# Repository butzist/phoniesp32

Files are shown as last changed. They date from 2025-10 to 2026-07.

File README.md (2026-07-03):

# phoniesp32 🎶🔋

A **kid-friendly jukebox** powered by the **ESP32**, inspired by
[Phoniebox](https://phoniebox.de). Unlike the original Raspberry Pi–based
version, **phoniesp32** is designed to be **battery-operated, low-power, and
ultra-portable**.

> ⚠️ Work in Progress — Contributions, ideas, and wiring tips are very welcome!

---

## 📥 Download Latest Firmware

[Download Firmware](https://github.com/butzist/phoniesp32/actions) (download the
`firmware` artifact from the latest run on main)

## ✨ Features

- **ESP32-based jukebox**: replaces the Raspberry Pi with an ESP32-C6.
- **Low-power & battery-ready**: runs on a Li-ion cell with charging and
  buck-boost converter.
- **Bare-metal Rust firmware**: built on the [`embassy`](https://embassy.dev/)
  async embedded framework.
- **Rust-powered Web UI**: implemented with [Dioxus](https://dioxuslabs.com/)
  and served directly from the ESP32.
- **Audio transcoding & upload**: convert music files via the web frontend to
  IMA ADPCM, upload to device, and play back instantly.
- **RFID support**: scan S50 fobs with a MFRC522 module to trigger playlists.
- **Affordable**: target build cost **under 50 CHF**.

---

## 🛠 Components

- **MCU**: ESP32-C6
- **Charging/Power**: BQ24073 (Li-ion charger), TSP631000 (buck-boost converter)
- **Battery**: Li-ion cell (e.g. 18650)
- **Audio**: MAX98357 (I2S DAC + amplifier)
- **Storage**: SD card adapter
- **RFID**: MFRC522 module + S50 RFID fobs

---

## 🏗 Build Options

1. **[DIY Breakout Board Build](./docs/diy-build.md)** - Build using
   off-the-shelf breakout boards on a breadboard or prototype board (~25 CHF)
2. **[PCB Build](./docs/pcb-build.md)** - Build using a compact and robust
   custom PCB board (~30 CHF)
3. **[PCBWay Shared Project](https://www.pcbway.com/project/shareproject/PhoniESP32_v1_2_d32752ab.html)**
   Order PCB on PCBWay with optional partial assembly of basic parts. Tutorial
   TBD

### 🏆 Sponsored by PCBWay

I'm grateful to [PCBWay](https://www.pcbway.com) for sponsoring this project!

The PCB and assembly quality was excellent, and their BOM review caught a few
mistakes I made in component selection — super helpful. I used the sponsorship
to fix minor bugs from v1 (charging indicator) and produce a version that can be
hand soldered. I opted for partial assembly (resistors, capacitors, LEDs) and am
practicing soldering connectors and ICs myself. Update and tutorial TBD — while
waiting, check out my project on PCBWay's shared project platform.

<a href="https://www.pcbway.com/project/shareproject/PhoniESP32_v1_2_d32752ab.html">
    PCB from PCBWay
</a>

---

## 🚧 Project Status

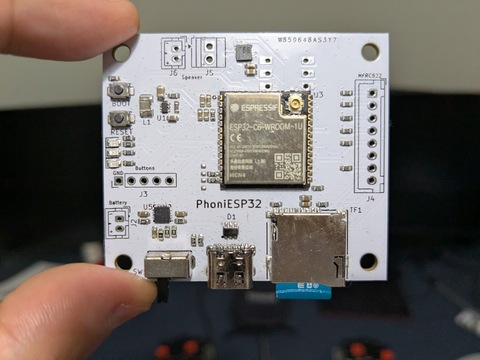
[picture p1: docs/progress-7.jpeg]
Photo of PCB

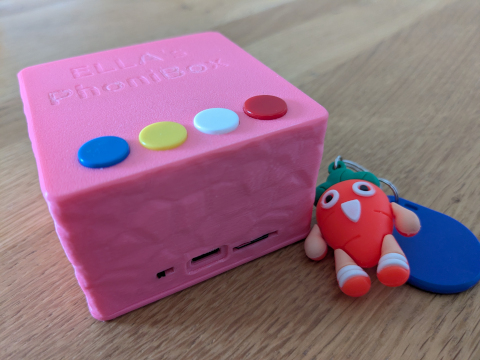
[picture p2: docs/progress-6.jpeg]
Photo of PCB integration


### Backlog

- [x] Hardware
  - [x] Prototype on breadboard
  - [x] Soldered Prototype
  - [x] Battery charger
  - [x] Schematics
  - [x] Custom PCB
  - [x] Design and 3D print case
- [x] UI (Dioxus)
  - [x] File transcoding
  - [x] Served from device
  - [x] Show last scanned RFID tag ID
  - [x] Switch to Bluma CSS
  - [x] Playback control
  - [x] Store RIFF INFO chunk for artist/title
  - [x] Associate file with RFID tag
  - [x] Configure Wi-Fi settings
  - [x] Playlists
  - [x] List known tags
  - [x] List uploaded files
  - [x] Continue file upload
  - [x] Styling
  - [x] Do not use CDN
  - [x] Update to stable Dioxus 0.7
- [ ] Firmware (Embassy)
  - [x] Fallback to Wi-Fi AP mode
  - [x] Audio pipeline (I2S → MAX98357)
  - [x] SD card access
  - [x] Playback control via buttons
  - [x] Playback control via RFID tags
  - [x] Pause playback
  - [x] Playlists
  - [x] Use RIFF INFO chunk for artist/title
  - [x] Fix concurrent access to file system
  - [x] mDNS responder
  - [x] Turn off Wi-Fi when on battery power
  - [x] Enable Wi-Fi temporarily by pressing volume up+down simultaneously for
        3s
  - [x] Captive portal and DHCP server for WiFi access point
  - [x] Speed up SD access/upload (SD card was bad - turns out cheap SD cards
        are bad at SPI)
  - [ ] Playback control via BLE
  - [x] SD card partitioning support
  - [x] Update to stable esp-hal 1.0
- [x] Web API (picoserve)
  - [x] Associate file with RFID tag
  - [x] Playback control
  - [x] Playback status
  - [x] Last scanned RFID tag ID
  - [x] Configure Wi-Fi settings
  - [x] List known tags
  - [x] List uploaded files
  - [x] Playlists
- [ ] Command line utility
  - [x] Transcode
  - [ ] Upload
  - [ ] Playback control
  - [ ] Associate
- [x] Build system
  - [x] Build and bundle all components
  - [x] Build via GitHub actions
- [ ] Upstream fixes
  - [ ] `dioxus`: Support sass:color.channel()
  - [x] `mfrc522`: async / IRQ support implemented in
        [mfrc522-async](https://github.com/butzist/mfrc522-async)
- [ ] Documentation
  - [x] [API Documentation](./API.md)
  - [x] [DIY Build Instructions](./docs/diy-build.md)
  - [ ] Hand soldering tutorial
  - [ ] Video tutorial

---

## 🤝 Contributing

Want to help build the cheapest, most fun, and hackable jukebox for kids?

- Review my code! I bet there are many possibilities to optimize power/memory
  usage
- Implement any of the missing features
- Share your ideas

PRs, issues, and ideas are always welcome!

---

## 📜 License

MIT License — free to use, hack, and share.

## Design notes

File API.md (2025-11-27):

# PhonieSP32 API Documentation

This document describes the REST API endpoints provided by the PhoniESP32
firmware web server.

## Base URL

All endpoints are relative to `http://<device-ip>`

**Default IP Address:** `192.168.42.1` (when device is in Access Point mode)

**Default WiFi Credentials:**

- SSID: `phoniesp32`
- Password: `12345678`

## Data Types

### AudioMetadata

```json
{
  "artist": "string (max 31 chars)",
  "title": "string (max 31 chars)",
  "album": "string (max 31 chars)",
  "duration": "number (seconds)"
}
```

### FileEntry

```json
{
  "name": "string (max 8 chars)",
  "metadata": "AudioMetadata"
}
```

### Association

```json
{
  "fob": "string (max 8 chars)",
  "files": ["FileEntry"]
}
```

### LastFob

```json
{
  "last_fob": "string (max 8 chars) or null"
}
```

### StatusResponse

```json
{
  "position_seconds": "number",
  "state": "Playing|Paused|Stopped",
  "index_in_playlist": "number",
  "playlist_name": "string (max 8 chars) or null"
}
```

### CurrentPlaylistResponse

```json
{
  "playlist_name": "string (max 8 chars)",
  "files": [{
    "file": "string (max 8 chars)",
    "metadata": "AudioMetadata"
  }]
}
```

### DeviceConfig

```json
{
  "ssid": "string",
  "password": "string"
}
```

## Endpoints

### Files

#### GET /api/files

List all audio files on the device.

**Response:** Array of `FileEntry`

#### GET /api/files/{filename}

Get metadata for a specific audio file.

**Parameters:**

- `filename`: string (max 8 chars, without .wav extension)

**Response:** `AudioMetadata` or 404 if not found

#### POST /api/files/{filename}

Create an empty audio file for chunked upload.

**Parameters:**

- `filename`: string (max 8 chars, without .wav extension)

**Response:** 201 Created on success

#### PATCH /api/files/{filename}

Upload a chunk of data to an existing audio file.

**Parameters:**

- `filename`: string (max 8 chars, without .wav extension)

**Headers:**

- `Upload-Offset`: number - Byte offset to start writing at

**Request Body:** Raw audio file chunk data

**Response:** 204 No Content on success, 404 if file doesn't exist, 400 if offset is larger than file size

#### HEAD /api/files/{filename}

Get the current size of an audio file.

**Parameters:**

- `filename`: string (max 8 chars, without .wav extension)

**Response Headers:**

- `Upload-Offset`: number - Current file size in bytes

**Response:** 200 OK on success, 404 if file doesn't exist

#### PUT /api/files/{filename}

Upload an entire audio file to the device (legacy endpoint).

**Parameters:**

- `filename`: string (max 8 chars, without .wav extension)

**Request Body:** Raw audio file data (WAV format, 44100 kHz, IMA ADPCM). Use
transcoder!

**Response:** 204 No Content on success

### Chunked Upload Workflow

For reliable file uploads with resume capability:

1. **Create file:** `POST /api/files/{filename}` - Creates empty file
2. **Upload chunks:** `PATCH /api/files/{filename}` with `Upload-Offset` header - Upload data in chunks
3. **On error:** Check progress with `HEAD /api/files/{filename}` and resume from last valid offset
4. **Repeat steps 2-3** until upload complete

**Example chunked upload with error handling:**
```bash
# Create empty file
curl -X POST http://192.168.42.1/api/files/song1

# Upload first chunk
curl -X PATCH http://192.168.42.1/api/files/song1 \
  -H "Upload-Offset: 0" \
  --data-binary @chunk1.bin

# Upload second chunk (simulating network error)
curl -X PATCH http://192.168.42.1/api/files/song1 \
  -H "Upload-Offset: 1024" \
  --data-binary @chunk2.bin || echo "Upload failed, checking progress..."

# Check current file size to resume from
CURRENT_SIZE=$(curl -I http://192.168.42.1/api/files/song1 | grep Upload-Offset | cut -d' ' -f2 | tr -d '\r')
echo "Current file size: $CURRENT_SIZE bytes"

# Resume upload from current size
curl -X PATCH http://192.168.42.1/api/files/song1 \
  -H "Upload-Offset: $CURRENT_SIZE" \
  --data-binary @chunk2.bin

# Continue with remaining chunks...
```

### Associations (RFID FOBs)

#### GET /api/last_fob

Get the last scanned RFID FOB.

**Response:** `LastFob`

#### GET /api/associations

List all FOB associations.

**Query Parameters:**

- `fob` (optional): Filter by specific FOB name

**Response:**

- Without `fob` parameter: Array of `Association`
- With `fob` parameter: Single `Association` or 404 if not found

#### POST /api/associations

Create a new FOB association.

**Request Body:**

```json
{
  "fob": "string (max 8 chars)",
  "files": ["string (max 8 chars)"]
}
```

**Response:** 204 No Content on success

### Playback Control

#### GET /api/playback/status

Get current playback status.

**Response:** `StatusResponse`

#### GET /api/playback/current_playlist

Get current playlist with metadata.

**Response:** `CurrentPlaylistResponse` or null if not playing

#### POST /api/playback/play

Start playback.

**Request Body:**

```json
{
  "file": "string (max 8 chars)", // Play single file
  // OR
  "playlist": ["string (max 8 chars)"], // Play list of files
  // OR
  "playlistref": "string (max 8 chars)" // Play playlist by FOB name
}
```

**Response:** 204 No Content on success

#### POST /api/playback/stop

Stop playback.

**Response:** 204 No Content on success

#### POST /api/playback/pause

Toggle pause/play state.

**Response:** 204 No Content on success

#### POST /api/playback/volume_up

Increase volume.

**Response:** 204 No Content on success

#### POST /api/playback/volume_down

Decrease volume.

**Response:** 204 No Content on success

#### POST /api/playback/next

Skip to the next track in the current playlist.

**Response:** 204 No Content on success

#### POST /api/playback/previous

Skip to the previous track in the current playlist.

**Response:** 204 No Content on success

### Configuration

#### PUT /api/config

Update device configuration (WiFi settings).

**Request Body:** `DeviceConfig`

**Response:** 204 No Content on success

#### DELETE /api/config

Reset device configuration.

**Response:** 204 No Content on success

## Notes

- All string fields have maximum length limits as specified
- Audio files need to be transcoded with the Web UI or standalone transcoder
  tool in this project
- File names are limited to 8 characters (DOS 8.3 naming without extension)
- FOB names are also limited to 8 characters
- The device serves a web interface that uses these API endpoints

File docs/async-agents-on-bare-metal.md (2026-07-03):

# How to Use Async Actors on Bare Metal

Embedded development has a well-worn path: the superloop. You initialize
everything, then `while(1)` with a sequence of polling calls. It works for
blinking LEDs, but as soon as you need concurrent I/O (WiFi, SD card, RFID,
audio playback, button debouncing), things get gnarly.

```c
void loop() {
    check_buttons();      // blocking, 5ms
    poll_rfid();          // blocking, 100ms
    update_wifi();        // blocking, could be seconds
    led_blink();          // non-blocking, but timing drifts
    delay(10);            // waste
}
```

Enter the RTOS. FreeRTOS gives you real threads with preemptive scheduling. Each
"thing" gets its own stack, its own `while(1)`. Problem solved, right?

```c
void rfid_task(void *pv) {
    while(1) {
        poll_rfid();
        vTaskDelay(100 / portTICK_PERIOD_MS);
    }
}
void wifi_task(void *pv) { /* ... */ }
void audio_task(void *pv) { /* ... */ }
```

```mermaid
graph TB
    subgraph Superloop
        S["~512 bytes"]
    end
    subgraph "RTOS (per task)"
        T1["RFID: 4 KB"]
        T2["WiFi: 8 KB"]
        T3["Audio: 4 KB"]
        T4["Button: 2 KB"]
    end
```

But that cost adds up. Each RTOS task reserves a full stack — worst-case
allocation. On the ESP32 with 512 KB RAM, four tasks at 4-8 KB each is
noticeable. Worse: you're back to shared mutable state with mutexes, and if you
want composable state machines, you're hand-rolling them.

## The Actor Model

Languages like Erlang and Rust (with Tokio/Embassy) offer a different approach:
**actors**. Each actor is an independent async task that owns its state and
communicates via message passing, not shared memory. Erlang's OTP formalizes
this into supervisors, gen_servers, and the "let it crash" philosophy.

The trick? Async runtimes use cooperative multitasking with **a single stack per
executor**, not per task. Each task's state lives in a small Future struct —
often a few hundred bytes.

## Our Architecture: Four Layers

```mermaid
graph TB
    subgraph "main.rs"
        S[Spawner]
    end

    subgraph "Drivers (Hardware Abstraction)"
        A[Audio I2S]
        R[RFID MFRC522]
        C[Charger GPIO]
        I[Indicator LED]
        SD[SD Card FAT]
        RAD[WiFi Radio]
        BTN[Button GPIO]
    end

    subgraph "Controllers (Business Logic)"
        W[WiFi Manager]
        P[Playback Controller]
        B[Buttons]
        N[Network Controller]
    end

    subgraph "Services (Network)"
        WEB[HTTP Server<br/>picoserve]
        MDNS[mDNS]
        CP[Captive Portal]
    end

    subgraph "Entities (Pure Domain)"
        AF[AudioFile]
        PL[Playlist]
    end

    S --> A & R & C & I & SD & RAD & BTN
    A --> P
    R --> N
    C --> W
    I --> W
    SD --> P
    RAD --> W
    BTN --> B
    W --> N
    N --> WEB & MDNS & CP
    P --> PL & AF
    B -.->|commands| W
    B -.->|commands| P
```

**Drivers** wrap raw hardware with an async task and return a `Handle`.
**Controllers** receive Handles from drivers, implement state machines, and
orchestrate higher-level operations (like "play this playlist"). **Services**
are network-facing tasks that use a network `Stack` from the WiFi controller.
**Entities** are pure domain objects with no I/O.

## How Embassy Makes This Possible

[Embassy](https://embassy.dev) is an async executor for bare-metal embedded
Rust. It gives you the same `async/await` you'd use on the server, but with
`no_std`, no allocator required, and full interrupt integration. On the ESP32 it
runs on top of ESP-IDF's FreeRTOS (via `esp_rtos`), but the executor is
Embassy's — meaning zero-cost task switching.

```rust
// One stack for the executor. Hundreds of "tasks" multiplexed on it.
#[esp_rtos::main]
async fn main(spawner: Spawner) {
    // Init hardware
    let player = Player::new(i2s, dma, bclk, ws, dout, enable);
    let charger = Charger::new(charger_pin, level);
    let rfid = Rfid::new(spi, cs, irq, enable_pin).await;

    // Spawn driver tasks → get Handles
    let player_handle = PlaybackController::new(player, fs).spawn(&spawner);
    let charger_monitor = charger.spawn(&spawner);
    let rfid_handle = rfid.spawn(&spawner);

    // Spawn controllers with driver handles
    let wifi_handle = WifiManager::new().spawn(&spawner, radio_handle, ...);
    Buttons::new(btn_a, btn_b, btn_c, btn_d).spawn(&spawner, wifi_handle, player_handle);

    // Main loop stays minimal
    loop {
        rfid_handle.trigger_scan();
        match rfid_handle.wait_for_scan_result().await {
            RfidScanResult::Found(fob) => player_handle.play_playlist_ref(fob).await,
            _ => Timer::after(Duration::from_millis(500)).await,
        }
    }
}
```

The `#[embassy_executor::task]` macro turns each `async fn` into a state machine
stored in a static. Switching between tasks is just resuming a Future — no
context switch, no kernel trap, no cache invalidation.

## The Spawn/Handle Pattern

Every component in our system follows one pattern:

```rust
pub struct MyDriver { /* hardware fields */ }

impl MyDriver {
    pub fn new(pins...) -> Self { /* ... */ }

    pub fn spawn(self, spawner: &Spawner) -> MyHandle {
        // 1. Allocate sync primitives in static memory
        let channel = mk_static!(Channel<NoopRawMutex, Cmd, 4>, Channel::new());
        // 2. Spawn the task
        spawner.must_spawn(my_task(self.hardware, channel));
        // 3. Return a cloneable handle
        MyHandle { tx: channel.sender() }
    }
}

/// Cloneable, Send-safe API for external consumers
#[derive(Clone)]
pub struct MyHandle {
    tx: &'static Channel<NoopRawMutex, Cmd, 4>,
}

impl MyHandle {
    pub async fn do_thing(&self) {
        self.tx.send(Cmd::DoThing).await;
    }
}

#[embassy_executor::task]
async fn my_task(hw: Hardware, channel: &'static Channel<NoopRawMutex, Cmd, 4>) {
    loop {
        let cmd = channel.receive().await;
        match cmd {
            Cmd::DoThing => hw.do_thing().await,
        }
    }
}
```

This encapsulates the task completely. The consumer never touches hardware,
never holds a raw pointer, never worries about lifetime safety. The handle is
the **only** API. This makes testing trivial — you can mock the handle in tests
(or better, write integration tests against a real handle with a mocked hardware
backend).

## Choosing the Right Sync Primitive

The hardest part of async actor design is figuring out **which message-passing
primitive to use**. Here's our cheat sheet:

```mermaid
graph TD
    Q1{"Primary need?"}

    Q1 -->|"Notify / signal"| N1{"Carry data?"}
    N1 -->|No| S1["Signal&lt;()&gt;<br/>eg. RFID scan trigger"]
    N1 -->|Yes| S2["Signal&lt;T&gt;<br/>eg. player Skip signal"]

    Q1 -->|"Send messages"| M1{"Buffer?"}
    M1 -->|Yes| C1["Channel&lt;T, N&gt;<br/>eg. PlayerCommand stream"]
    M1 -->|No| C2["Signal&lt;T&gt;<br/>rendezvous hand-off"]

    Q1 -->|"Share state"| W1{"Multiple<br/>readers?"}
    W1 -->|Yes| WA["Watch&lt;T, N&gt;<br/>eg. ChargerState broadcast"]
    W1 -->|No| MU["Mutex&lt;T&gt;<br/>eg. SdFileSystem lock"]

    Q1 -->|"Lock-free flag"| A1["AtomicBool / AtomicU8<br/>eg. wifi_is_active, volume"]

    style S1 fill:#e3f2fd
    style S2 fill:#e3f2fd
    style C1 fill:#fff3e0
    style C2 fill:#e3f2fd
    style WA fill:#f3e5f5
    style MU fill:#e8f5e9
    style A1 fill:#fce4ec
```

When the decision is driven by lifetime patterns rather than producer count,
reach for higher-level primitives:

| Primitive | When to use |
| --- | --- |
| **Signal** (no buffer, rendezvous) | Wake a task. One-shot notification with or without a payload. Example: `skip_signal` fires `Skip::Next`/`Skip::Prev` into the playback task. |
| **Channel** (buffered queue) | Commands and data streams. The playback controller sends `PlayerCommand::Stop` into a `Channel<..., 2>`. The audio decoder produces `AudioPacket::Buffer` into a `Channel<..., 1>` for the I2S output task. |
| **Watch** (broadcast, retains last value) | Observable state. The charger GPIO task `sender.send(Connected)` and three consumers read via `receiver.changed()`. New subscribers always get the latest value immediately. |
| **Mutex** (async, `no_std`) | Exclusive access to a shared resource. The SD card filesystem is guarded by `Mutex<SdFileSystem>` — only one task reads/writes at a time. |
| **Atomic** | Lock-free flags. `AtomicBool` for "is WiFi active?" (polled from the main loop). `AtomicU8` for volume (read by the decoder task, written by the controller task). |

## Built to be Testable

Because every actor communicates through a typed `Handle`, testing is
straightforward:

- **Unit-test entities** — pure functions on `AudioFile`, `Playlist`, etc.
- **Test a controller** — give it a mock Handle that records commands instead of
  talking to hardware.
- **Integration-test drivers** — run the real task against a loopback handle.

No hardware stubs, no global state teardown, no linker script hacks. The handle
is the seam.

## Why This Beats Both Superloop and RTOS

```mermaid
graph TB
    subgraph Superloop
        P1["Sequential — hard to compose"]
        P2["Timing coupling"]
        P3["No concurrency"]
    end
    subgraph RTOS
        P4["N stacks — high memory"]
        P5["Preemption = racy"]
        P6["Context switch overhead"]
    end
    subgraph "Async Actors"
        S1["Cooperative — safe"]
        S2["Single stack — low memory"]
        S3["Zero-cost await"]
    end
```

| | Classic Arduino | RTOS (FreeRTOS) | Async Actors (Embassy) |
| --- | --- | --- | --- |
| **Memory per task** | Single stack (~512 B) | Full stack (2-8 KB) | Future state (bytes to hundreds of bytes) |
| **Concurrency model** | Sequential, polling | Preemptive threads | Cooperative async |
| **Inter-task communication** | Global variables | Queues + mutexes | Typed channels, signals, watchers |
| **State machine composability** | Hand-rolled enums + switch | Hand-rolled enums + switch | `select3`, `join`, `with_timeout` |
| **Testing** | Hardware-in-loop | Hardware-in-loop | Handle mocking, async test harness |
| **Sleep/power save** | Manual, error-prone | Manual, error-prone | `select` + timeout → natural light sleep  |

## The Stack

ESP32, Embassy (async executor), `esp_hal` (peripherals), picoserve (HTTP),
heapless (static containers), static_cell (static allocation). Fully `no_std`,
nightly Rust.

The full source is available at
[github.com/butzist/phoniesp32](https://github.com/anomalyco/phoniesp32) — a
WiFi audio player for kids that uses RFID fobs to trigger playlist playback.
Every driver, controller, and service follows the spawn/handle pattern described
here.

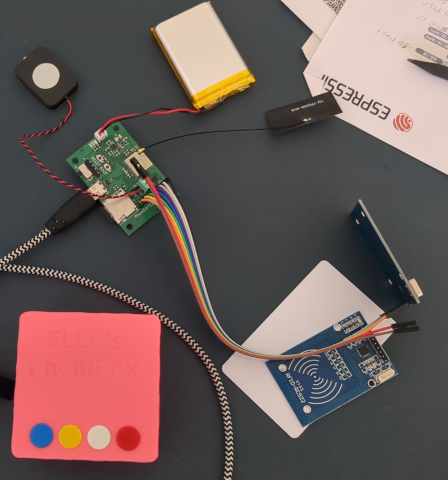
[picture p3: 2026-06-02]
docs/pcb/peripherals.jpeg

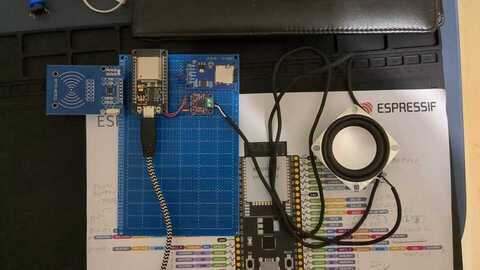
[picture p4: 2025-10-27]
docs/progress-2.jpeg

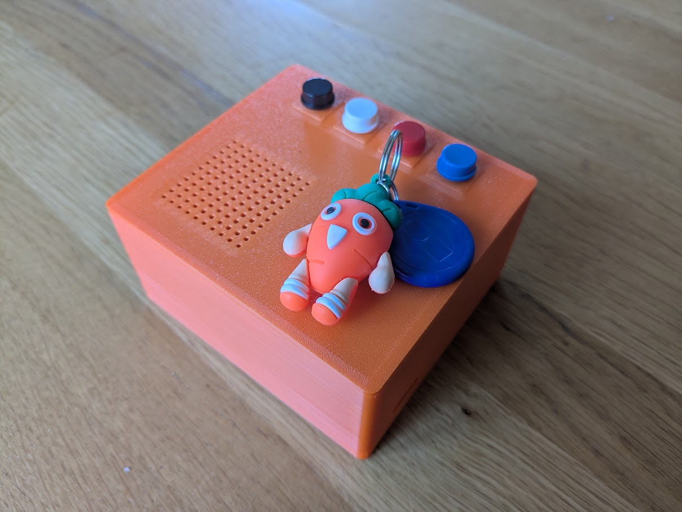
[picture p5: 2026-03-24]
docs/progress-4.jpeg

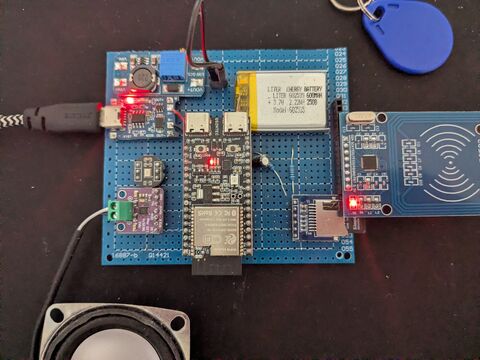
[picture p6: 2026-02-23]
docs/progress-3.jpeg

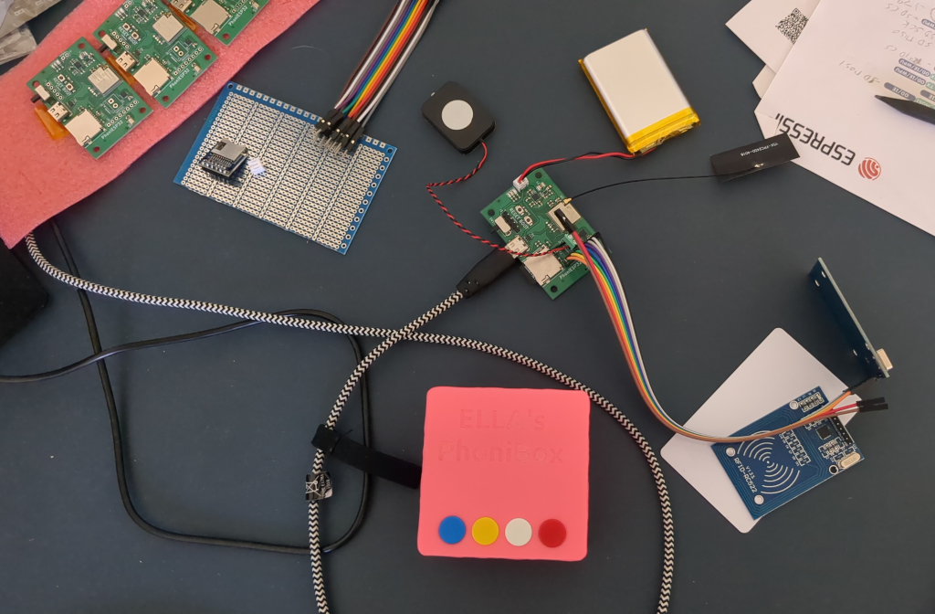
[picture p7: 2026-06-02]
docs/progress-5.jpeg

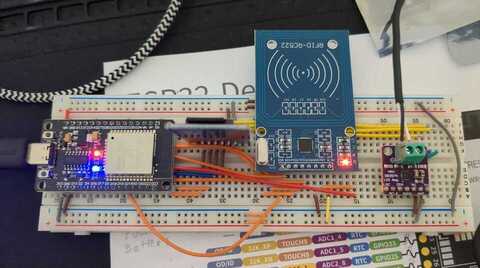
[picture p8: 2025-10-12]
docs/progress-1.jpeg

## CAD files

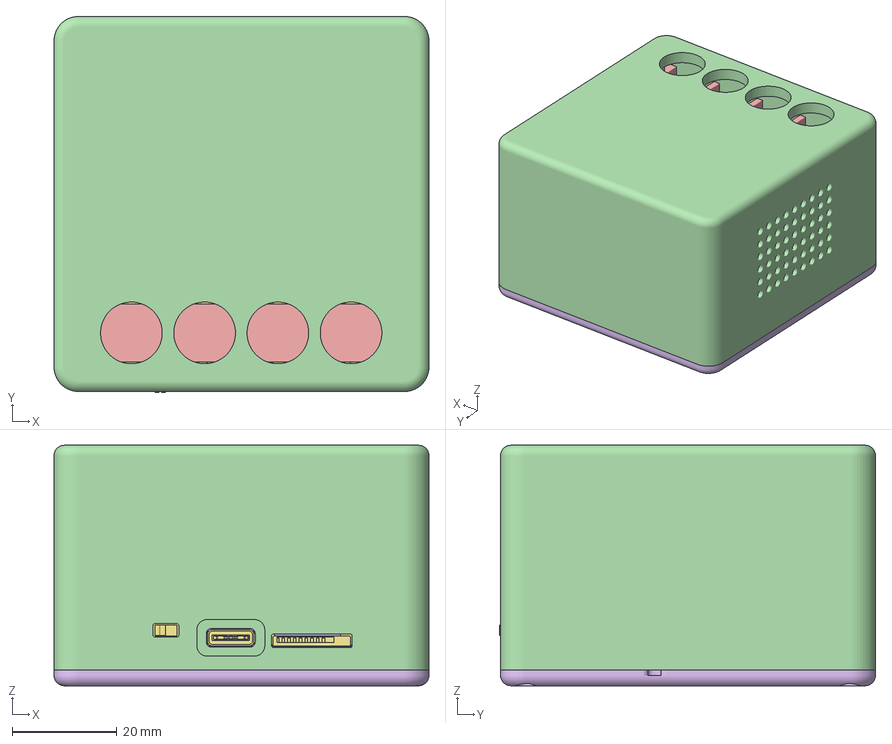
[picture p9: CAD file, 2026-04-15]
case/PCBCase.FCStd
71.7 x 71.9 x 46.0 mm
MFRC522
Speaker
Battery
Top
ButtonHolder
Bottom
Board

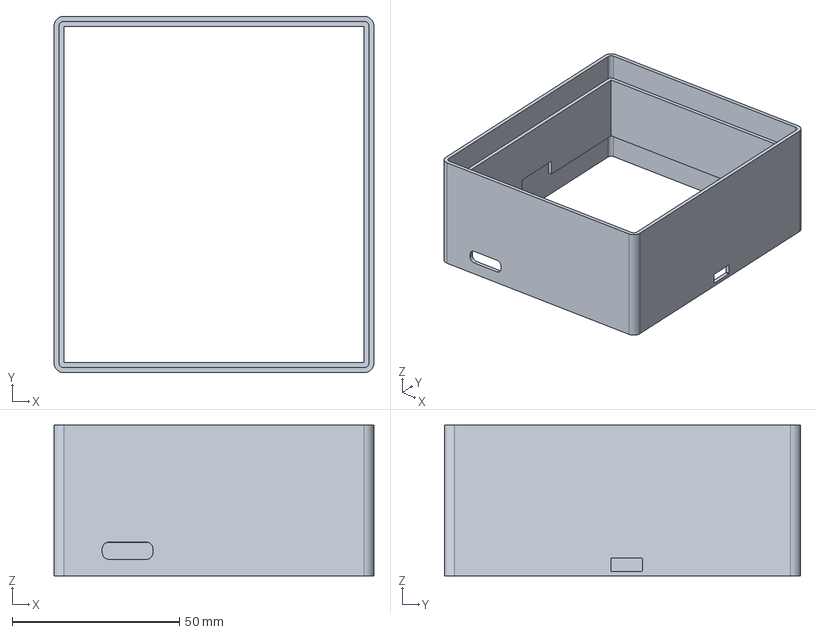
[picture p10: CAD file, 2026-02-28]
case/PrototypeCase.FCStd
95.6 x 106.5 x 45.0 mm

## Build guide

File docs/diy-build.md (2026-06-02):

# DIY Build Instructions - Prototype Board

Build your own **PhoniESP32** jukebox using breakout boards! This guide walks
you through assembling the prototype on a breadboard or prototype board.

> **Note**: These instructions are for the breadboard/prototype board version.
> For a more compact and robust solution, see the [PCB build guide](pcb-build.md).

---

## Parts List

All components are available on Aliexpress for under **25 CHF** total.

| Component | Quantity | Aliexpress Link |
| --- | --- | --- |
| ESP32-C6 DevKit | 1 | [1005008777558392](https://aliexpress.com/item/1005008777558392.html) |
| TP4056 (Li-ion charger) | 1 | [32621399438](https://aliexpress.com/item/32621399438.html) |
| MT3608 (5V boost converter) | 1 | [1005010193381334](https://aliexpress.com/item/1005010193381334.html) |
| 18650 LiPo cell (3.7V, 600mAh+)  | 1 | [1005009121905266](https://aliexpress.com/item/1005009121905266.html) |
| MAX98357A (I2S DAC + amplifier)  | 1 | [1005010587934639](https://aliexpress.com/item/1005010587934639.html) |
| SD card adapter (SPI) | 1 | [1005008870179318](https://aliexpress.com/item/1005008870179318.html) |
| MFRC522 (RC522 clone) + S50 tags | 1 | [1005006264253080](https://aliexpress.com/item/1005006264253080.html) |
| 4 Ohm 3W speaker | 1 | [1005010804698010](https://aliexpress.com/item/1005010804698010.html) |
| SD card | 1 | - |
| Breadboard or prototype board | 1 | - |
| Jumper wires | ~20 | - |

**Optional**:

- RFID keychain figures: [Amazon DE](https://www.amazon.de/dp/B097P3QPVK)
- RFID tags (S50): [Amazon DE](https://www.amazon.de/-/en/dp/B01IH7Y9CM)

**Note**:

- Some cheaper and older SD cards have trouble speaking the SPI protocol. They
  can be slow or not work at all.

---

## Wiring Diagram

Breakout Boards Wiring Diagram

---

## Assembly Steps

### 1. Power Circuit

1. **Connect battery to TP4056**:
   - `B+` → Battery positive (typically red wire)
   - `B-` → Battery negative (typically black wire)

2. **Connect MT3608 boost converter**:
   - `IN+` → TP4056 `OUT+`
   - `IN-` → TP4056 `OUT-`
   - Adjust the potentiometer to output **5V**

3. **Power distribution**:
   - Connect 5V from MT3608 to ESP32 `VIN` (or 5V pin)
   - Connect GND to all components

### 2. ESP32-C6 Connections

| ESP32-C6 Pin | Connected To |
| --- | --- |
| `3V3` | MAX98357 VCC, MFRC522 VCC, SD adapter VCC |
| `GND` | Common ground |
| `GPIO0` | Button: Pause |
| `GPIO1` | Button: Next/Prev |
| `GPIO2` | Button: Volume up |
| `GPIO3` | Button: Volume down |
| `GPIO4` | USB power detection via voltage divider |
| `GPIO5` | SPI `MISO` |
| `GPIO6` | SPI `MOSI` |
| `GPIO7` | SPI `SCK` |
| `GPIO10` | SD adapter `CS` |
| `GPIO15` | I2S `WS` |
| `GPIO18` | MFRC522 `SDA` |
| `GPIO19` | MFRC522 `IRQ` |
| `GPIO22` | I2S `DOUT` |
| `GPIO23` | I2S `BCLK` |

### 3. MFRC522 RFID Module

The RC522 module uses SPI interface:

- `SDA` → `GPIO18`
- `SCK` → `GPIO7`
- `MOSI` → `GPIO6`
- `MISO` → `GPIO5`
- `RST` → NC
- `GND` → `GND`
- `IRQ` → `GPIO19`
- `3.3V` → `3V3`

### 4. SD Card Adapter

SD card adapter connections:

- `CS` → `GPIO10`
- `MOSI` → `GPIO6`
- `SCK` → `GPIO7`
- `MISO` → `GPIO5`
- `VCC` → `3V3`
- `GND` → `GND`

### 5. MAX98357A I2S DAC

- `LRC` → `GPIO15`
- `BCLK` → `GPIO23`
- `DIN` → `GPIO22`
- `GAIN` → `GND`
- `SD` → `3V3`
- `GND` → `GND`
- `Vin` → `3V3`

Connect to speaker:

- `+` → Speaker positive
- `-` → Speaker negative

---

## Flash Firmware

1. Download the latest firmware:
   ```bash
   # Download from releases
   wget https://github.com/butzist/phoniesp32/releases/download/v1.0.0/firmware.bin
   ```

   Or build from source:
   ```bash
   git clone https://github.com/butzist/phoniesp32.git
   cd phoniesp32
   nix develop
   cd firmware && just build --pinout prototype
   ```

2. Install `espflash` if not already installed:
   ```bash
   # Download from GitHub releases
   # or install via cargo: cargo install espflash
   ```

3. Flash the firmware:
   ```bash
   espflash flash --chip esp32c6 firmware/target/riscv32imac-unknown-none-elf/release/firmware
   ```

4. **Important**: Connect the device to a power source (USB or charger). The
   device will not start the wireless AP unless powered.

---

## Prepare SD Card

If not already formatted (which it should be by default), format the SD card as
**FAT32** with an MBR partition table. Note: FAT32 cannot store files larger
than 4GB.

### Linux

```bash
# Create partition table and FAT32 partition
fdisk /dev/sdX  # Use 'o' to create DOS partition table, 'n' for new partition, 't' to set type to FAT32, 'w' to write
mkfs.vfat /dev/sdX1  # Format the partition
```

### macOS

**GUI (Disk Utility)**:

1. Open Disk Utility (Applications → Utilities)
2. Select your SD card
3. Click "Erase"
4. Choose **"MS-DOS (FAT)"** as the format
5. Click "Erase"

**Terminal**:

```bash
diskutil list  # Find your SD card (e.g., disk2)
sudo diskutil eraseDisk FAT32 PHONIESP32 MBRFormat /dev/disk2
```

### Windows

**GUI**:

1. Open File Explorer, right-click on the SD card
2. Select "Format"
3. Choose **FAT32** as filesystem (only available for cards ≤32GB)
4. Click "Start"

**Command Line (any size)**:

```powershell
# Run as Administrator
diskpart  # Use 'list disk', 'select disk X', 'clean', 'create partition primary', 'format fs=fat32 quick', 'assign'
```

**Cards >32GB**: Windows doesn't natively support FAT32 for larger cards.
Download [FAT32 Format](https://www.ridgecrop.demon.co.uk/guiformat.htm)
(guiformat.exe)

- Run as Administrator, select your drive, click "Start"

2. Insert the SD card into the adapter.

---

## First Boot

1. Power on the device (must be plugged into charger/power)
2. The device creates a Wi-Fi access point:
   - **SSID**: `phoniesp32`
   - **Password**: `12345678`
3. Connect to the AP
4. Open a browser and navigate to:
   - [http://phoniesp32](http://phoniesp32) or
   - [http://phoniesp32.local](http://phoniesp32.local)

5. On the **Settings** page, enter your Wi-Fi credentials
6. Reboot the device - it will now connect to your Wi-Fi when powered

---

## Usage

1. **Upload music**: Navigate to the web interface and transcode/upload audio
   files
2. **Scan RFID tags**: Assign songs/playlists to RFID tags
3. **Playback control**: Use the web UI or physical buttons (if wired)

---

## Troubleshooting

| Issue | Solution |
| --- | --- |
| No AP appears | Ensure device is powered (plugged into charger) |
| Can't connect to AP | Check SSID/password, try forgetting network first |
| Not booting | Ensure SD card is formatted correctly |
| No audio | Check speaker connections |
| RFID not working | Verify SPI connections, ensure MFRC522 is properly seated. Ensure no conductive plane above or below. |

---

## Access Logs

To view real-time logs from the device, use either:

### Using just (recommended)

```bash
cd firmware
just run       # Flash and monitor
# or
just monitor   # Just monitor (if already flashed)
```

### Using espflash directly

```bash
espflash monitor --chip esp32c6 --log-format defmt --elf firmware/target/riscv32imac-unknown-none-elf/release/firmware
```

> **Tip**: Logs are useful for troubleshooting startup issues, Wi-Fi connection
> problems, and RFID errors.

---

## Next Steps

- [x] Design and 3D print a case
- [x] Design custom PCB for a more compact build ([guide](pcb-build.md))

---

_Build cost: ~25 CHF | Runtime: Multiple hours on battery_

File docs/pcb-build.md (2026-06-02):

# Build Instructions - Custom PCB (Second Prototype)

Build your own **PhoniESP32** jukebox with a custom PCB! This guide walks you
through assembling the compact PCB-based version.

> **Note**: These instructions are for the custom PCB version. For the
> breadboard/prototype board version, see `./diy-build.md`.

## Photo of final assembly

## Parts List

### PCB + SMD Components

The PCB and all SMD components can be ordered from JLCPCB/PCBWay/DigiKey/etc (I
ordered from JLCPCB for ca. **20 CHF** per piece for 5 pieces including
components and assembly). The KiCad project is available in the `pcb/`
directory. In theory you can also just order a PCB and hand solder all
components.

| Component | Quantity | Notes |
| --- | --- | --- |
| PhoniESP32 PCB | 1 | KiCad project in `pcb/` |
| ESP32-C6-MINI-1U-H4 | 1 | |
| BQ24073RGTR (battery charger)  | 1 | |
| TPS631000DRLR (3.3V regulator) | 1 | |
| MAX98357AETE+T (I2S DAC) | 1 | |
| USBLC6-2SC6 (ESD protection) | 1 | |
| DFE252012P-1R0M (inductor) | 1 | |
| SK12D07VG5 (power switch) | 1 | |
| TF-CARD H1.8 (microSD slot) | 1 | |
| USB Type-C connector | 1 | |
| Resistors & capacitors | ~20 | |
| SPH0645LM4H (microphone) | 1 | Optional |

### Components You Need to Source

| Component | Quantity | Example Link |
| --- | --- | --- |
| 18650 LiPo cell (3.7V, 3000mAh) | 1 | [Aliexpress](https://aliexpress.com/item/1005009240348340.html) |
| MFRC522 (RC522 clone) + S50 tags  | 1 | [Aliexpress](https://aliexpress.com/item/1005006264253080.html) |
| 4 Ohm 3W full-range speaker | 1 | [Aliexpress](https://aliexpress.com/item/1005008626624201.html) |
| External 2.4GHz antenna (IPX-3) | 1 | [Aliexpress](https://aliexpress.com/item/1005005890848674.html) |
| Tactile Push Buttons | 4 | [Aliexpress](https://aliexpress.com/item/1005011897486277.html) |
| SD card | 1 | - |
| Pin header (2.54mm, 8P) for J4 | 1 | Optional - for RC522 |
| Pin header (2.54mm, 5P) for J3 | 1 | Optional - for buttons |
| Pin header (2.54mm, 2P) for J2 | 1 | Optional - for battery connector |
| Screw terminal (3.5mm, 2P) for J5 | 1 | Optional - for speaker |
| Dupont cables (female-female) | 5 | For connecting buttons |
| M2.5 screws and brass inserts | 6 each | For mounting in case |

**Optional**:

- RFID keychain figures: [Amazon DE](https://www.amazon.de/dp/B097P3QPVK)
- RFID tags (S50): [Amazon DE](https://www.amazon.de/-/en/dp/B01IH7Y9CM)

---

## Connector Overview

The PCB has populated and unpopulated connector footprints:

| Ref | Type | Pins | Purpose | Populated? |
| --- | --- | ---- | --- | --- |
| J1  | USB Type-C (SMD) | 16 | Power & data | Yes |
| J2  | Pin header, 2.54mm | 2 | Battery | DNP |
| J3  | Pin header, 2.54mm | 5 | Buttons | DNP |
| J4  | Pin header/socket, 2.54mm | 8 | RC522 | DNP |
| J5  | Screw terminal, 3.5mm | 2 | Speaker | DNP |

### J2 Pinout (2-pin, 2.54mm) - Battery

| Pin | Signal | Connected To |
| --- | --- | --- |
| 1 | BAT+ | Battery positive (red) |
| 2 | BAT- | Battery negative (black) |

### J3 Pinout (5-pin, 2.54mm) - Buttons

| Pin | Signal | Connected To |
| --- | --- | --- |
| 1 | GND | One side of all buttons |
| 2 | Button 1 | Pause button |
| 3 | Button 2 | Next/Prev button |
| 4 | Button 3 | Volume down button |
| 5 | Button 4 | Volume up button |

### J4 Pinout (8-pin, 2.54mm) - RC522

| Pin | Signal | Connected To |
| --- | --- | --- |
| 1 | SDA/CS | RC522 `SDA` |
| 2 | SCK | RC522 `SCK` |
| 3 | MOSI | RC522 `MOSI` |
| 4 | MISO | RC522 `MISO` |
| 5 | IRQ | RC522 `IRQ` |
| 6 | GND | RC522 `GND` |
| 7 | EN | RC522 `ENABLE` |
| 8 | 3.3V | RC522 `VCC` |

---

## Assembly Steps

### 1. Ordering the PCB

1. Open the KiCad project in `pcb/PhoniESP32/`
2. Generate Gerber files (File → Fabrication → Gerbers or with manufacturing
   plugin)
3. Upload to JLCPCB/PCBWay/DigiKey/etc and order PCB
4. Optional: Select the SMT assembly service with the components listed above

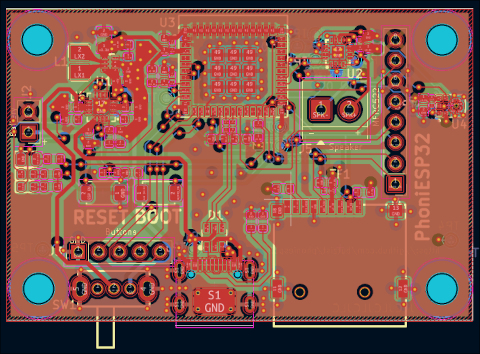
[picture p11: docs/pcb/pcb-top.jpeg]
Photo of PCB top


### 2. Solder Connectors (J2, J3, J4, J5)

These are marked DNP (Do Not Populate) by default. Solder them based on your
preferred wiring method:

**J2 (2-pin, battery)**:

- Solder a JST PH socket, or
- If your battery doesn't have a JST PH connector, solder directly, or use a
  screw terminal

**J3 (5-pin, buttons)**:

- Solder a 5-pin male pin header
- Buttons are connected with female-to-male DuPont cables to each pin

**J4 (8-pin, RC522)**:

- Solder an 8-pin female pin socket (for easy plugging of RC522) or male
  pin/JST/Molex header if you want to mount the RC522 on the lid, like I did.

**J5 (2-pin, speaker screw terminal)**:

- Solder the 2-pin screw terminal for easy speaker connection

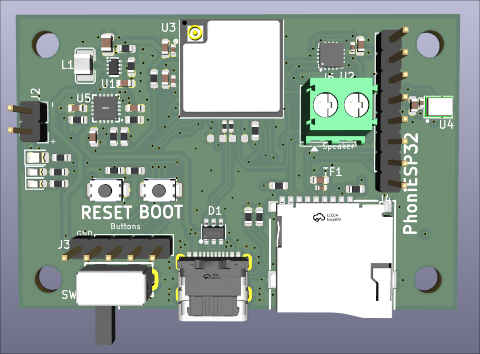
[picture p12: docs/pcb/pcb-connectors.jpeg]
Photo of connectors soldered


### 3. Attach Heat Inserts to Case

The case design uses M2.5 brass heat inserts. Instructions for installing them:

1. Print the case parts from `case/` directory:
   - `PCBCase-Top.stl`
   - `PCBCase-Bottom.stl`
   - `PCBCase-ButtonHolder.stl`
2. Heat up a soldering iron to ~200°C
3. Place the heat insert on the designated hole in the printed part
4. Press down gently with the soldering iron tip until the insert is flush with
   the surface
5. Repeat for all mounting holes

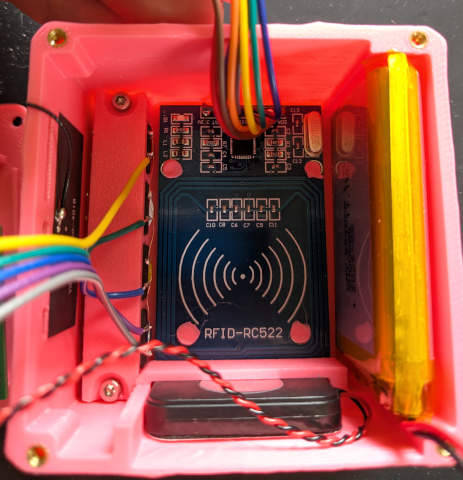
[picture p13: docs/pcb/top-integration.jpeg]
Photo of top integration


### 4. Mount PCB and RC522 in Case

1. The design has mounting pins that can be melted over the modules with a
   soldering iron for a secure fit
2. Secure the PCB to the case bottom by melting the mounting pins
3. Mount the RC522 module under the case top in the same way

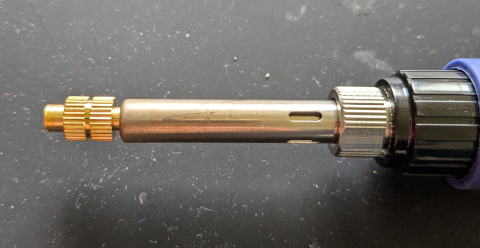
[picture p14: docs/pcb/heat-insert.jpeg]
Photo of heat insert tool


### 5. Connect RC522 RFID Module

1. Wire the RC522 module to J4 using the pinout table above
2. A female-female DuPont cable or custom harness works well
3. Keep the connections short and tidy.

### 6. Connect Buttons

Each button connects between GND and the corresponding signal pin on J3. All
buttons share a common GND.

| Button | J3 Pin |
| --- | --- |
| GND (common) | 1 |
| Pause | 2 |
| Next/Prev | 3 |
| Volume + | 4 |
| Volume - | 5 |

Solder one side of all buttons to a common GND wire, then connect the other side
of each button to its respective J3 pin using individual wires.

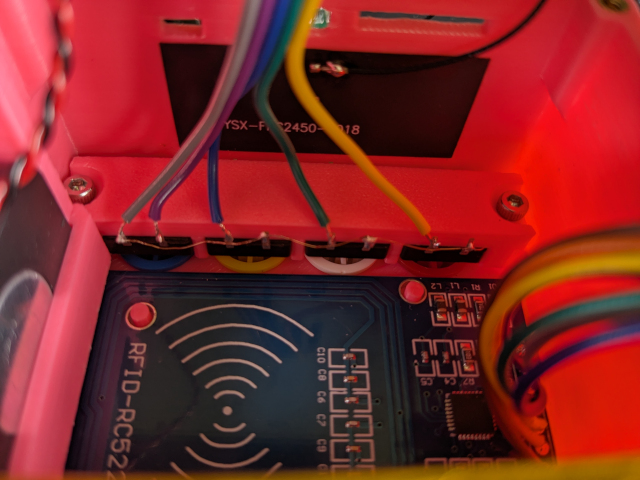
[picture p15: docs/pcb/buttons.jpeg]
Photo of button wiring


### 7. Connect Battery

If the battery has a JST PH 2.0mm connector, it plugs directly into J2. If not,
wire it to the 2-pin header:

- Battery `+` (red) → J2 pin 1
- Battery `-` (black) → J2 pin 2

**Warning**: Double-check polarity before connecting!

### 8. Connect External Antenna

The ESP32-C6-MINI-1U module has an IPX connector for an external antenna.
Connect the IPX-3 PCB antenna to the module.

### 9. Connect Speaker

- The speaker connects to J5 (screw terminal)
- Mount the speaker on the side of the case using the designated mounting
  points.

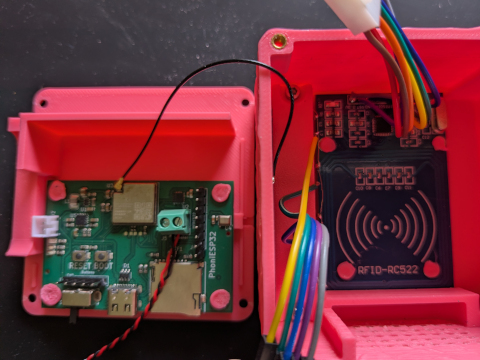
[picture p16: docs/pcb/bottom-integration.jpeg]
Photo of bottom integration


### 10. Final Assembly

1. Place the battery in the case
2. Route all wires neatly to avoid pinching
3. Close the case and secure with screws
4. Insert the FAT32-formatted SD card

Photo of final assembly

---

## Flash Firmware

1. Download the latest firmware:
   ```bash
   wget https://github.com/butzist/phoniesp32/releases/download/v1.1.0/firmware.zip
   unzip firmware.zip
   ```

   Or build from source:
   ```bash
   git clone https://github.com/butzist/phoniesp32.git
   cd phoniesp32
   nix develop
   cd firmware && just build
   ```

2. Install `espflash` (download from
   [GitHub releases](https://github.com/esp-rs/espflash/releases/tag/v4.3.0) or
   via package manager)

3. Flash the firmware:
   ```bash
   espflash flash --chip esp32c6 firmware
   ```

4. **Important**: Connect the device to a power source (USB or charger). The
   device will not start the wireless AP unless powered.

---

## Prepare SD Card

If not already formatted, format the SD card as **FAT32** with an MBR partition
table.

### Linux

```bash
mkfs.vfat /dev/sdX1
```

### macOS

```bash
sudo diskutil eraseDisk FAT32 PHONIESP32 MBRFormat /dev/disk2
```

### Windows

Use DiskPart or FAT32 Format (guiformat.exe) for cards >32GB.

Insert the SD card into the PCB's microSD slot.

---

## First Boot

1. Power on the device (plug into USB or flip the power switch)
2. The device creates a Wi-Fi access point:
   - **SSID**: `phoniesp32`
   - **Password**: `12345678`
3. Connect to the AP
4. Open a browser and navigate to:
   - [http://phoniesp32](http://phoniesp32) or
   - [http://phoniesp32.local](http://phoniesp32.local)
5. On the **Settings** page, enter your Wi-Fi credentials
6. Reboot the device - it will now connect to your Wi-Fi when powered

---

## Usage

1. **Upload music**: Navigate to the web interface and transcode/upload audio
   files
2. **Scan RFID tags**: Assign songs/playlists to RFID tags
3. **Playback control**: Use the web UI, RFID scanning, or physical buttons

---

## Troubleshooting

| Issue | Solution |
| --- | --- |
| No AP appears | Ensure device is powered (USB or battery with switch on) |
| Can't connect to AP | Check SSID/password, device will fall back to starting as AP |
| Not booting | Ensure SD card is formatted correctly |
| No audio | Check speaker connections to J5 |
| RFID not working | Verify J4 connections, ensure RC522 is properly seated and not obstructed by close-by conductive material |
| Poor WiFi range | Ensure external antenna is connected to the IPX connector and not obstructed by close-by conductive material |

---

## Access Logs

```bash
cd firmware
just run       # Flash and monitor
# or
just monitor   # Just monitor (if already flashed)
```

Or using espflash directly:

```bash
espflash monitor --chip esp32c6 --log-format defmt --elf firmware/target/riscv32imac-unknown-none-elf/release/firmware
```

---

_Build cost: ~30-35 CHF | Runtime: Multiple days on 3000mAh battery_

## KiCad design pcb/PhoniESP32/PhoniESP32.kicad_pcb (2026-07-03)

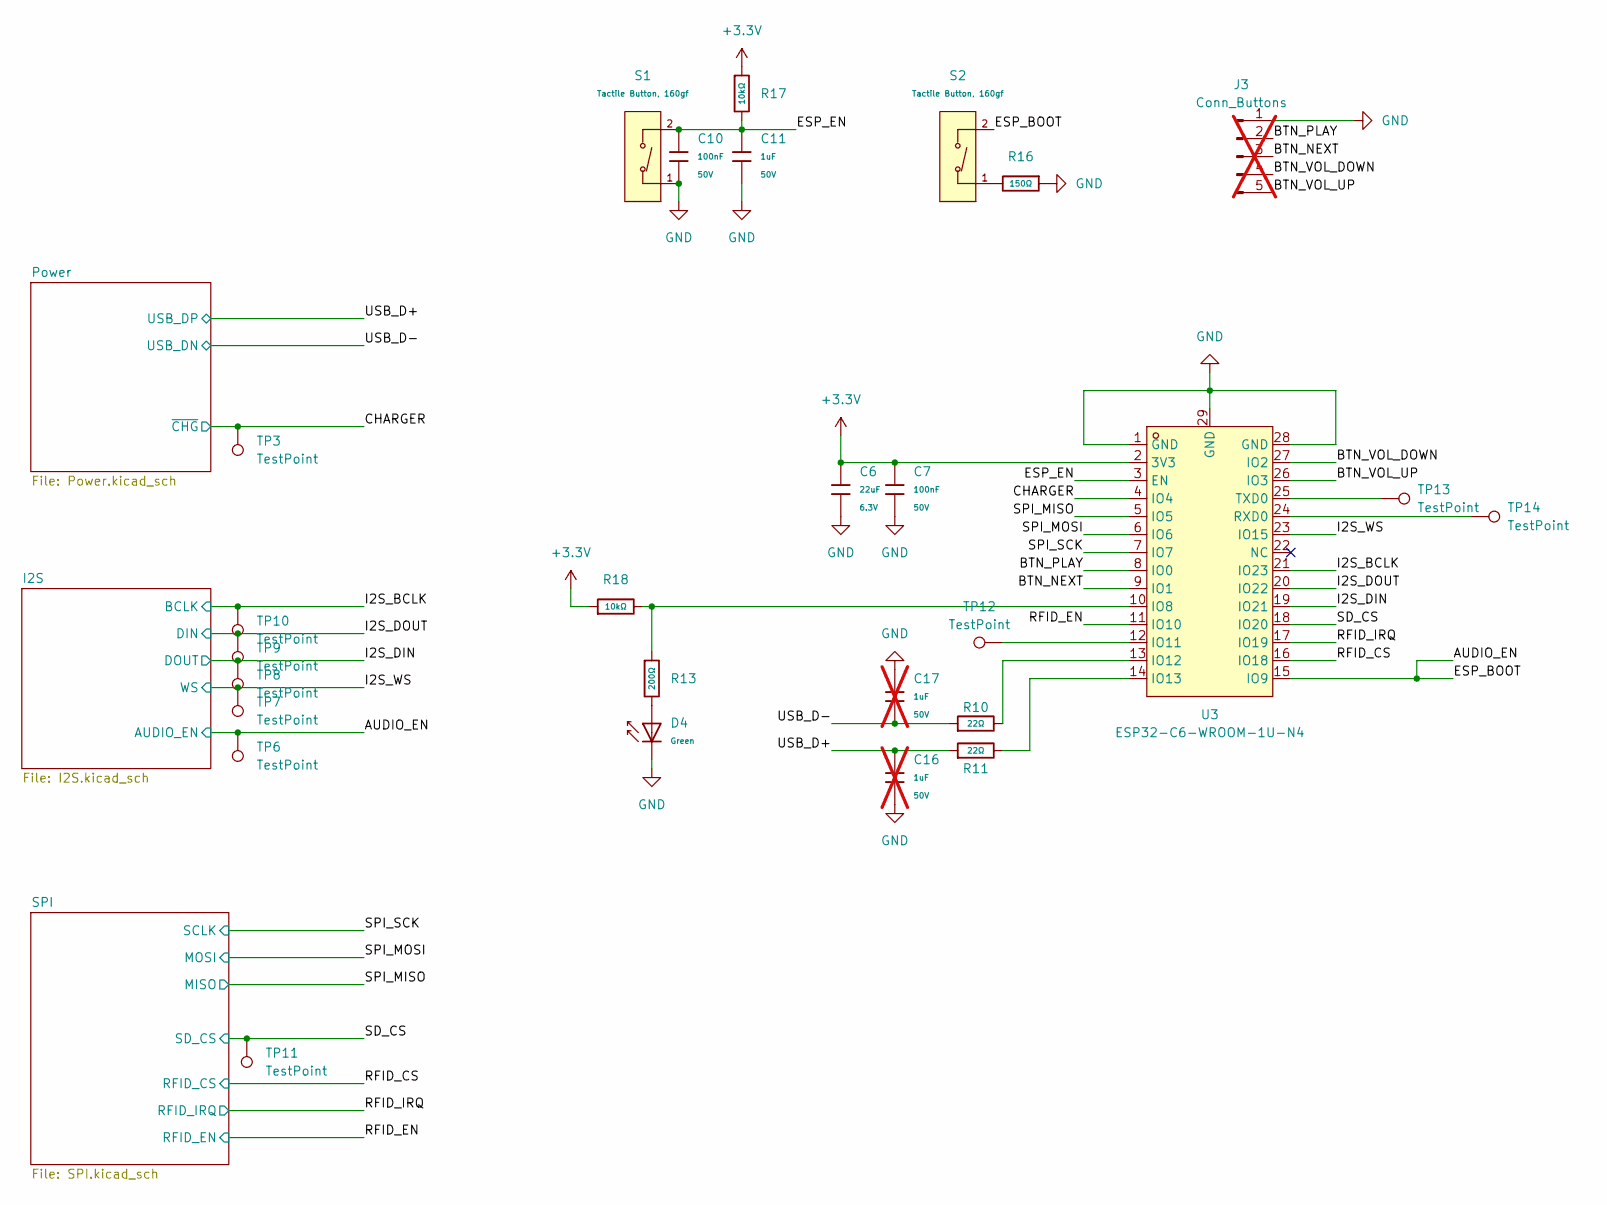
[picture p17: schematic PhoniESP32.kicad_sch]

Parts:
C6: 22uF; C_0603; Voltage Rated 6.3V; Tolerance ±20%; Part CL10A226MQ8NRNC; LCSC C59461
C7, C10: 100nF; C_0603; Voltage Rated 50V; Tolerance ±10%; Part CC0603KRX7R9BB104; LCSC C14663
C11: 1uF; C_0603; Voltage Rated 50V; Tolerance ±10%; Part CL10A105KB8NNNC; LCSC C15849
C16, C17: 1uF; C_0603; Voltage Rated 50V; Tolerance ±10%; Part CL10A105KB8NNNC; LCSC C15849; not fitted
D4: Green; D_0805; Part KT-0805G; LCSC C2297
J3: Conn_Buttons; PinHeader_1x05_P2.54mm_Vertical; MPN A2541WV-5P; LCSC Part C225480; not fitted
R10, R11: 22Ω; R_0603; Overload Voltage (Max) 75V; Tolerance ±1%; Part 0603WAF220JT5E; LCSC C23345
R13: 200Ω; R_0603; Overload Voltage (Max) 75V; Tolerance ±1%; Part 0603WAF2000T5E; LCSC C8218
R16: 150Ω; R_0603; Overload Voltage (Max) 75V; Tolerance ±1%; Part 0603WAF1500T5E; LCSC C22808
R17, R18: 10kΩ; R_0603; Overload Voltage (Max) 75V; Tolerance ±1%; Part 0603WAF1002T5E; LCSC C25804
S1, S2: Tactile Button, 160gf; SW_TS-1088-AR02016; Voltage Rating (Dc) 12V; Part TS-1088-AR02016; LCSC C720477
TP3, TP6, TP7, TP8, TP9, TP10, TP11, TP12, TP13, TP14: TestPoint; TestPoint_Pad_D1.0mm
U3: ESP32-C6-WROOM-1U-N4; WIFIM-SMD_28P-L19.2-W18.0-P1.27-TL; MPN ESP32-C6-WROOM-1U-N4; LCSC Part C19272929

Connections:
+3.3V: C6.1, C7.1, R17.1, R18.1, U3.2 (3V3); also elsewhere on the board
/AUDIO_EN: S2.2 (B), TP6.1 (1_1), U3.15 (IO9); also elsewhere on the board
/BTN_NEXT: J3.3, U3.9 (IO1)
/BTN_PLAY: J3.2, U3.8 (IO0)
/BTN_VOL_DOWN: J3.4, U3.27 (IO2)
/BTN_VOL_UP: J3.5, U3.26 (IO3)
/CHARGER: TP3.1 (1_1), U3.4 (IO4); also elsewhere on the board
/ESP_EN: C10.1, C11.1, R17.2, S1.2 (B), U3.3 (EN)
/I2S_BCLK: TP10.1 (1_1), U3.21 (IO23); also elsewhere on the board
/I2S_DIN: TP8.1 (1_1), U3.19 (IO21); also elsewhere on the board
/I2S_DOUT: TP9.1 (1_1), U3.20 (IO22); also elsewhere on the board
/I2S_WS: TP7.1 (1_1), U3.23 (IO15); also elsewhere on the board
/RFID_CS: U3.16 (IO18); also elsewhere on the board
/RFID_EN: U3.11 (IO10); also elsewhere on the board
/RFID_IRQ: U3.17 (IO19); also elsewhere on the board
/SD_CS: TP11.1 (1_1), U3.18 (IO20); also elsewhere on the board
/SPI_MISO: U3.5 (IO5); also elsewhere on the board
/SPI_MOSI: U3.6 (IO6); also elsewhere on the board
/SPI_SCK: U3.7 (IO7); also elsewhere on the board
/USB_D+: C16.1, R11.1; also elsewhere on the board
/USB_D-: C17.1, R10.1; also elsewhere on the board
GND: C6.2, C7.2, C10.2, C11.2, C16.2, C17.2, D4.1, J3.1, R16.1, S1.1 (A), U3.1 (GND), U3.28 (GND), U3.29 (GND); also elsewhere on the board
unnamed: D4.2, R13.2
unnamed: R16.2, S2.1 (A)
unnamed: R13.1, R18.2, U3.10 (IO8)
unnamed: TP12.1 (1_1), U3.12 (IO11)
unnamed: R10.2, U3.13 (IO12)
unnamed: R11.2, U3.14 (IO13)
unnamed: TP14.1 (1_1), U3.24 (RXD0)
unnamed: TP13.1 (1_1), U3.25 (TXD0)

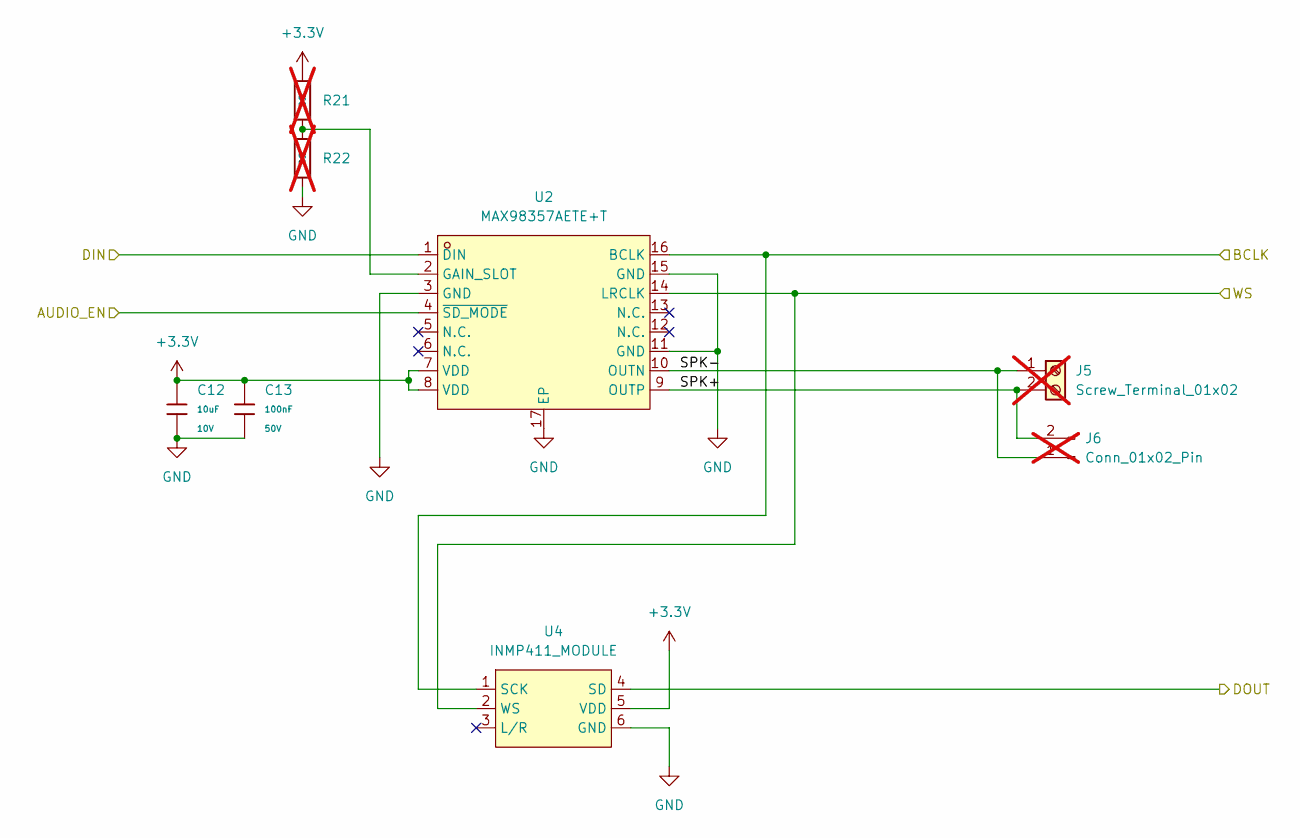
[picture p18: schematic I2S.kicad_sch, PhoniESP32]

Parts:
C12: 10uF; C_0603; Voltage Rated 10V; Tolerance ±10%; Part CL10A106KP8NNNC; LCSC C19702
C13: 100nF; C_0603; Voltage Rated 50V; Tolerance ±10%; Part CC0603KRX7R9BB104; LCSC C14663
J5: Screw_Terminal_01x02; TerminalBlock_Xinya_XY308-2.54-2P_1x02_P2.54mm_Horizontal; not fitted
J6: Conn_01x02_Pin; JST_PH_B2B-PH-K_1x02_P2.00mm_Vertical; MPN B2B-PH-K-S(LF)(SN); LCSC Part C131337; not fitted
R21, R22: 0Ω; R_0603; Overload Voltage (Max) 75V; Tolerance ±1%; Part 0603WAF0000T5E; LCSC C21189; not fitted
U2: MAX98357AETE+T; TQFN-16_L3.0-W3.0-P0.50-BL-EP1.5; MPN MAX98357AETE+T; LCSC Part C910544
U4: INMP411_MODULE

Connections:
+3.3V: C12.1, C13.1, R21.1, U2.7 (VDD), U2.8 (VDD), U4.5 (VDD); also elsewhere on the board
/AUDIO_EN: U2.4 (~SD_MODE); also elsewhere on the board
/I2S/SPK+: J5.2, J6.2, U2.9 (OUTP)
/I2S/SPK-: J5.1, J6.1, U2.10 (OUTN)
/I2S_BCLK: U2.16 (BCLK), U4.1 (SCK); also elsewhere on the board
/I2S_DIN: U4.4 (SD); also elsewhere on the board
/I2S_DOUT: U2.1 (DIN); also elsewhere on the board
/I2S_WS: U2.14 (LRCLK), U4.2 (WS); also elsewhere on the board
GND: C12.2, C13.2, R22.2, U2.3 (GND), U2.11 (GND), U2.15 (GND), U2.17 (EP), U4.6 (GND); also elsewhere on the board
unnamed: R21.2, R22.1, U2.2 (GAIN_SLOT)

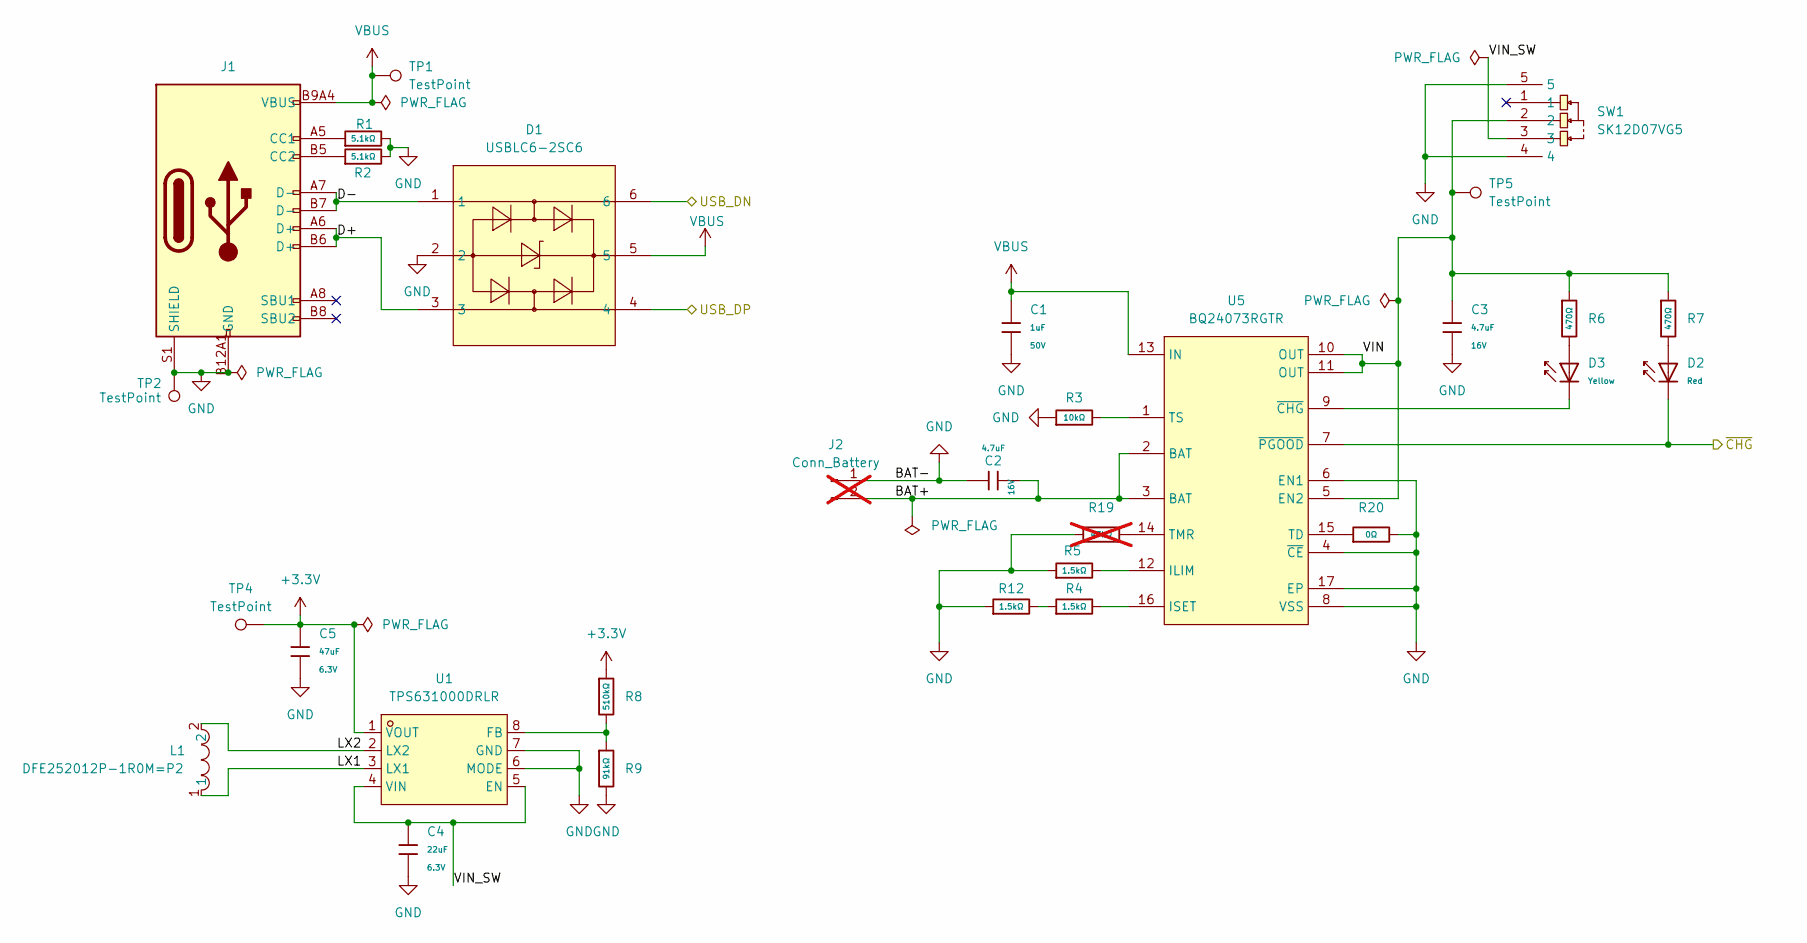
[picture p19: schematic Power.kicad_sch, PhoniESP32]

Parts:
C1: 1uF; C_0603; Voltage Rated 50V; Tolerance ±10%; Part CL10A105KB8NNNC; LCSC C15849
C2, C3: 4.7uF; C_0603; Voltage Rated 16V; Tolerance ±10%; Part CL10A475KO8NNNC; LCSC C19666
C4: 22uF; C_0603; Voltage Rated 6.3V; Tolerance ±20%; Part CL10A226MQ8NRNC; LCSC C59461
C5: 47uF; C_0805; Voltage Rated 6.3V; Tolerance ±20%; Part CL21A476MQYNNNE; LCSC C16780
D1: USBLC6-2SC6; SOT-23-6_L2.9-W1.6-P0.95-LS2.8-BL; MPN USBLC6-2SC6; LCSC Part C7519
D2: Red; D_0805; Forward Voltage (VF) 1.6V~2.6V; Part NCD0805R1; LCSC C84256
D3: Yellow; D_0805; Forward Voltage (VF) 1.6V~2.6V; Part KT-0805Y; LCSC C2296
J1: Connector, USB-TYPE-C-16P; TYPE-C-SMD_HX-TYPE-C-16PIN; MPN USB-TYPE-C-019; LCSC C2927039
J2: Conn_Battery; JST_PH_B2B-PH-K_1x02_P2.00mm_Vertical; MPN B2B-PH-K-S(LF)(SN); LCSC Part C131337; not fitted
L1: DFE252012P-1R0M=P2; L1008; MPN DFE252012P-1R0M=P2; LCSC Part C882955
R1, R2: 5.1kΩ; R_0603; Overload Voltage (Max) 75V; Tolerance ±1%; Part 0603WAF5101T5E; LCSC C23186
R3: 10kΩ; R_0603; Overload Voltage (Max) 75V; Tolerance ±1%; Part 0603WAF1002T5E; LCSC C25804
R4, R5, R12: 1.5kΩ; R_0603; Overload Voltage (Max) 75V; Tolerance ±1%; Part 0603WAF1501T5E; LCSC C22843
R6, R7: 470Ω; R_0603; Overload Voltage (Max) 75V; Tolerance ±1%; Part 0603WAF4700T5E; LCSC C23179
R8: 510kΩ; R_0603; Overload Voltage (Max) 75V; Tolerance ±1%; Part 0603WAF5103T5E; LCSC C23192
R9: 91kΩ; R_0603; Overload Voltage (Max) 75V; Tolerance ±1%; Part 0603WAF9102T5E; LCSC C23265
R19: 47kΩ; R_0603; Overload Voltage (Max) 75V; Tolerance ±1%; Part 0603WAF4702T5E; LCSC C25819; not fitted
R20: 0Ω; R_0603; Overload Voltage (Max) 75V; Tolerance ±1%; Part 0603WAF0000T5E; LCSC C21189
SW1: SK12D07VG5; SW-TH_SK12D07VG5-1; MPN SK12D07VG5; LCSC Part C431548
TP1, TP2, TP4, TP5: TestPoint; TestPoint_Pad_D1.0mm
U1: TPS631000DRLR; SOT-583-8_L2.1-W1.2-P0.50-LS1.6-BL; MPN TPS631000DRLR; LCSC Part C5219190
U5: BQ24073RGTR; QFN-16_L3.0-W3.0-P0.50-TL-EP1.7; MPN BQ24073RGTR; LCSC Part C15220

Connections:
+3.3V: C5.1, R8.1, TP4.1 (1_1), U1.1 (VOUT); also elsewhere on the board
/CHARGER: D2.1, U5.7 (~PGOOD); also elsewhere on the board
/Power/BAT+: C2.1, J2.2, U5.2 (BAT), U5.3 (BAT)
/Power/D+: D1.3, J1.A6 (D+), J1.B6 (D+)
/Power/D-: D1.1, J1.A7 (D-), J1.B7 (D-)
/Power/LX1: L1.1, U1.3 (LX1)
/Power/LX2: L1.2, U1.2 (LX2)
/Power/VIN: C3.1, R6.1, R7.1, SW1.2, TP5.1 (1_1), U5.5 (EN2), U5.10 (OUT), U5.11 (OUT)
/Power/VIN_SW: C4.1, SW1.3, U1.4 (VIN), U1.5 (EN)
/USB_D+: D1.4; also elsewhere on the board
/USB_D-: D1.6; also elsewhere on the board
GND: C1.2, C2.2, C3.2, C4.2, C5.2, D1.2, J1.A12B1 (GND), J1.B12A1 (GND), J1.S1 (SHIELD), J2.1, R1.2, R2.2, R3.1, R5.1, R9.2, R12.1, R19.1, R20.2, SW1.4, SW1.5, TP2.1 (1_1), U1.6 (MODE), U1.7 (GND), U5.4 (~CE), U5.6 (EN1), U5.8 (VSS), U5.17 (EP); also elsewhere on the board
unnamed: D2.2, R7.2
unnamed: D3.2, R6.2
unnamed: J1.A5 (CC1), R1.1
unnamed: J1.B5 (CC2), R2.1
unnamed: R4.1, R12.2
unnamed: R8.2, R9.1, U1.8 (FB)
unnamed: R5.2, U5.12 (ILIM)
unnamed: R4.2, U5.16 (ISET)
unnamed: R20.1, U5.15 (TD)
unnamed: R19.2, U5.14 (TMR)
unnamed: R3.2, U5.1 (TS)
unnamed: D3.1, U5.9 (~CHG)
VBUS: C1.1, D1.5, J1.A9B4 (VBUS), J1.B9A4 (VBUS), TP1.1 (1_1), U5.13 (IN)

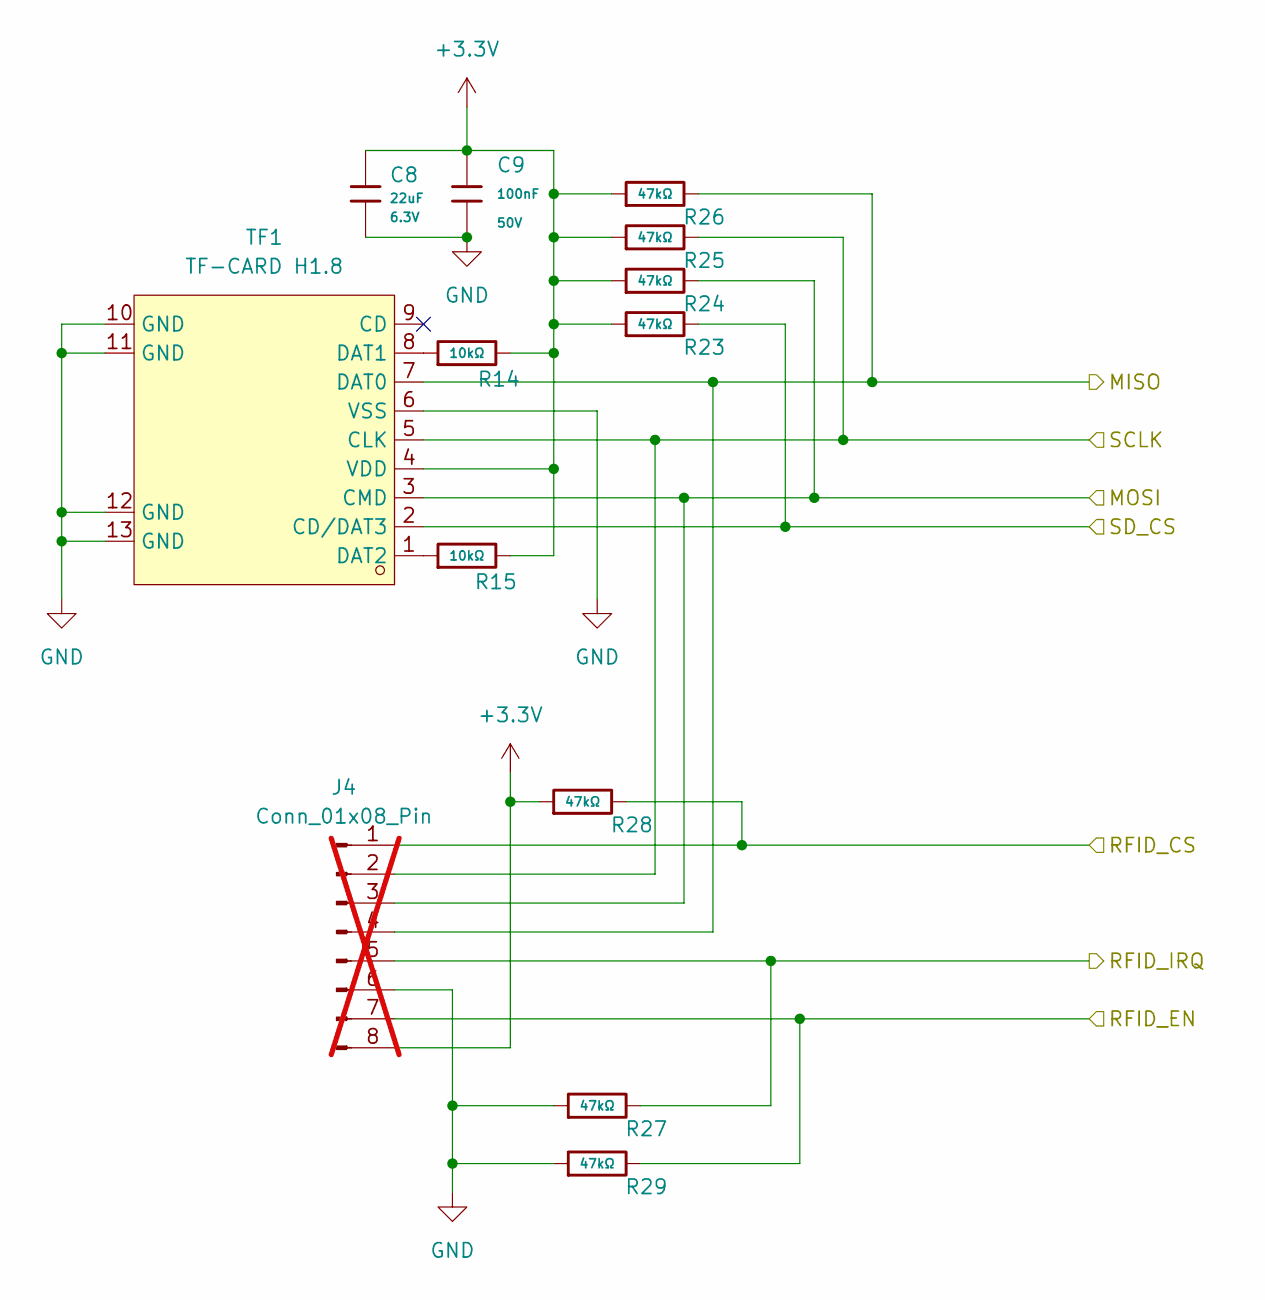
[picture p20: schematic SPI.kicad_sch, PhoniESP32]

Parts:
C8: 22uF; C_0603; Voltage Rated 6.3V; Tolerance ±20%; Part CL10A226MQ8NRNC; LCSC C59461
C9: 100nF; C_0603; Voltage Rated 50V; Tolerance ±10%; Part CC0603KRX7R9BB104; LCSC C14663
J4: Conn_01x08_Pin; JST_XH_B8B-XH-A_1x08_P2.50mm_Vertical; MPN B8B-XH-A(LF)(SN); LCSC Part C157972; not fitted
R14, R15: 10kΩ; R_0603; Overload Voltage (Max) 75V; Tolerance ±1%; Part 0603WAF1002T5E; LCSC C25804
R23, R24, R25, R26, R27, R28, R29: 47kΩ; R_0603; Overload Voltage (Max) 75V; Tolerance ±1%; Part 0603WAF4702T5E; LCSC C25819
TF1: TF-CARD H1.8; TF-SMD_TF-CARD-H1.8; MPN TF-CARD H1.8; LCSC Part C7529389

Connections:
+3.3V: C8.1, C9.1, J4.8, R14.2, R15.2, R23.1, R24.1, R25.1, R26.1, R28.1, TF1.4 (VDD); also elsewhere on the board
/RFID_CS: J4.1, R28.2; also elsewhere on the board
/RFID_EN: J4.7, R29.2; also elsewhere on the board
/RFID_IRQ: J4.5, R27.2; also elsewhere on the board
/SD_CS: R23.2, TF1.2 (CD/DAT3); also elsewhere on the board
/SPI_MISO: J4.4, R26.2, TF1.7 (DAT0); also elsewhere on the board
/SPI_MOSI: J4.3, R24.2, TF1.3 (CMD); also elsewhere on the board
/SPI_SCK: J4.2, R25.2, TF1.5 (CLK); also elsewhere on the board
GND: C8.2, C9.2, J4.6, R27.1, R29.1, TF1.6 (VSS), TF1.10 (GND), TF1.11 (GND), TF1.12 (GND), TF1.13 (GND); also elsewhere on the board
unnamed: R14.1, TF1.8 (DAT1)
unnamed: R15.1, TF1.1 (DAT2)

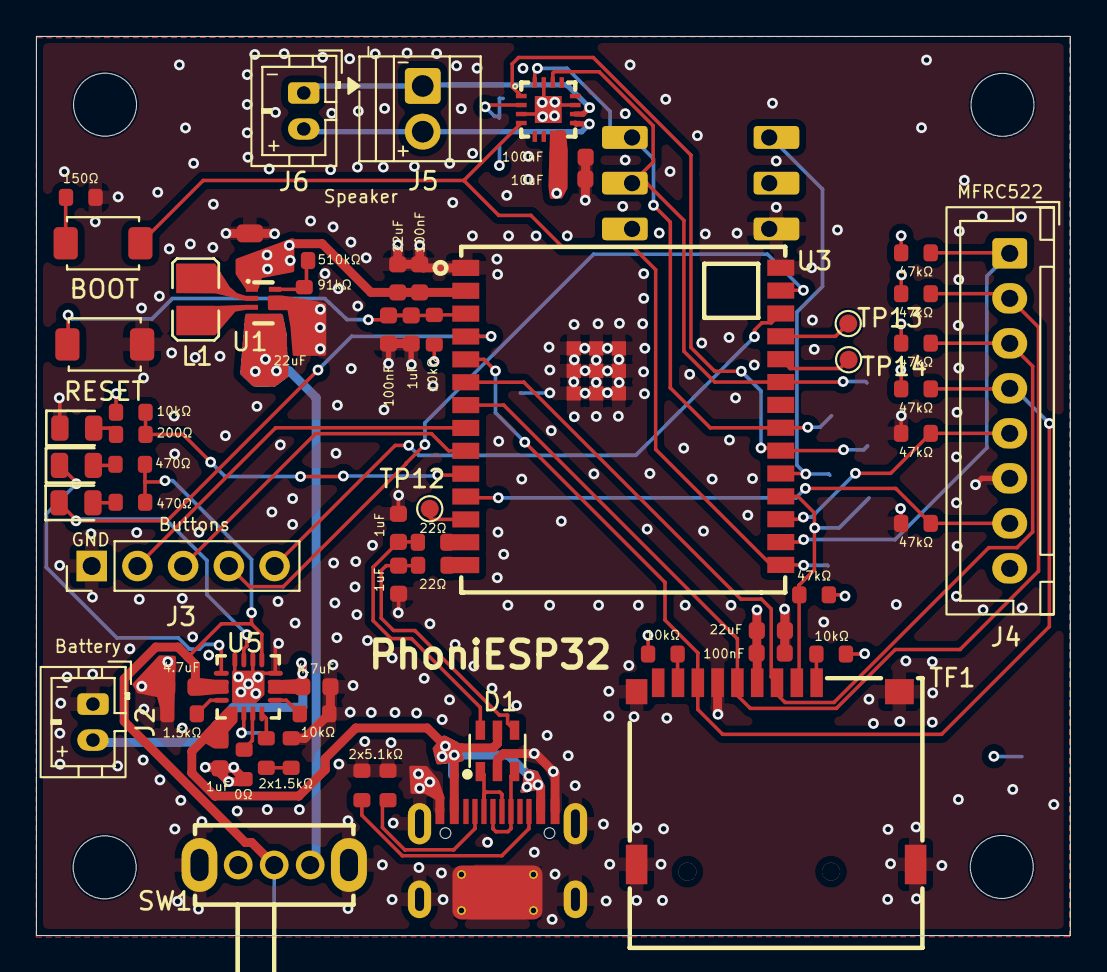
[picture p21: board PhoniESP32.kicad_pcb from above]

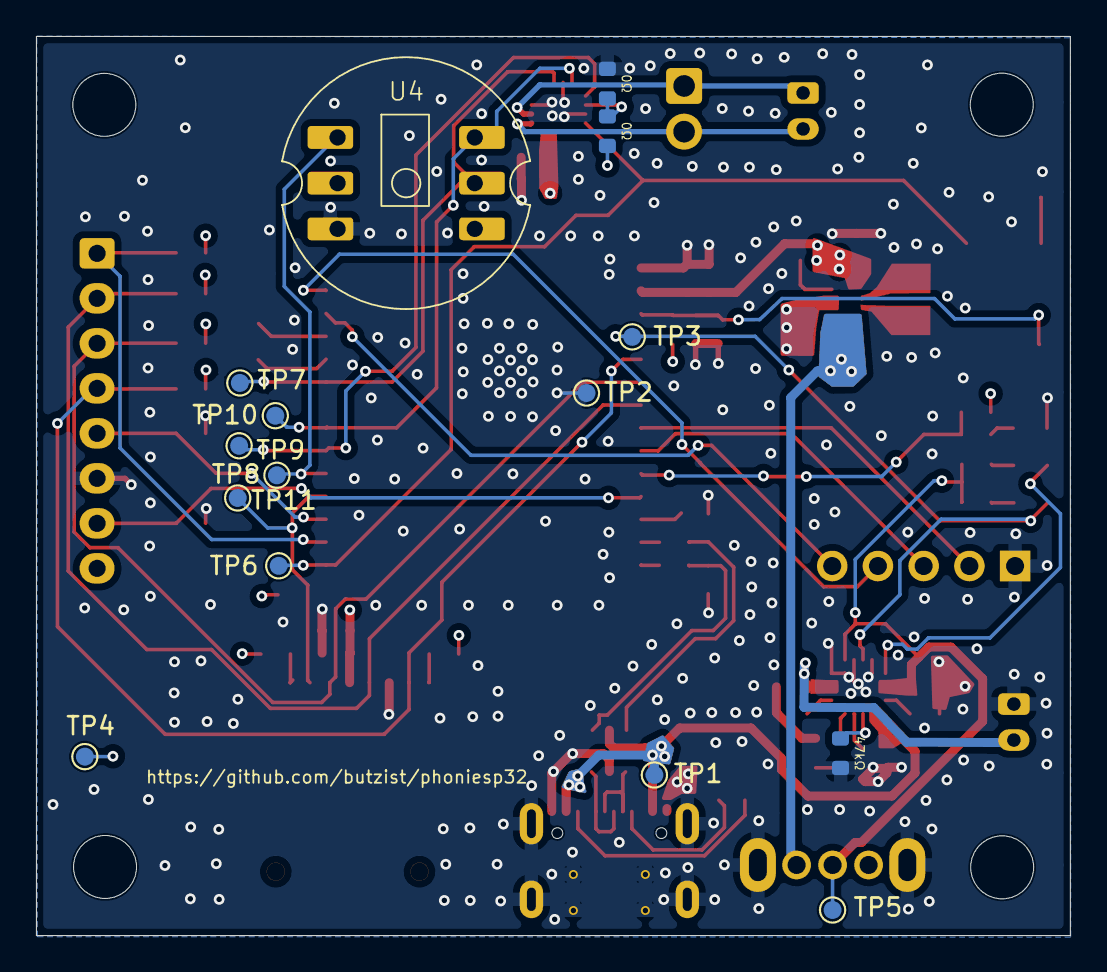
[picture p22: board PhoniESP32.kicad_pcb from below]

Board: 4 copper layers, 57.4 x 49.9 mm, 78 parts (15 on the bottom side), 55 nets.

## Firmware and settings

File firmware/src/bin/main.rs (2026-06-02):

#![no_std]
#![no_main]
#![deny(
    clippy::mem_forget,
    reason = "mem::forget is generally not safe to use with esp_hal types, especially those \
    holding buffers for the duration of a data transfer."
)]
use core::cell::RefCell;
use defmt::{debug, info};
use embassy_executor::Spawner;
use embassy_time::{Duration, Timer};
use esp_hal::clock::CpuClock;
use esp_hal::dma::DmaChannelConvert;
use esp_hal::interrupt::software::SoftwareInterruptControl;
use esp_hal::rtc_cntl::Rtc;
use esp_hal::rtc_cntl::sleep::{GpioWakeupSource, TimerWakeupSource};
use esp_hal::system::{SleepSource, wakeup_cause};
use esp_hal::timer::timg::TimerGroup;
use firmware::controllers::buttons::Buttons;
use firmware::controllers::network::NetworkController;
use firmware::controllers::playback::PlaybackController;
use firmware::controllers::playback::status::State;
use firmware::drivers::audio::Player;
use firmware::drivers::charger::Charger;
use firmware::drivers::control_button::Button;
use firmware::drivers::indicator::IndicatorLed;
use firmware::drivers::rfid::Rfid;
use firmware::drivers::sd::{Sd, SdFsWrapper};
use firmware::drivers::spi_bus;
use firmware::mk_static;
use firmware::peripherals::create_peripherals;
use {esp_backtrace as _, esp_println as _};

extern crate alloc;

// This creates a default app-descriptor required by the esp-idf bootloader.
// For more information see: <https://docs.espressif.com/projects/esp-idf/en/stable/esp32/api-reference/system/app_image_format.html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>
esp_bootloader_esp_idf::esp_app_desc!();

#[esp_rtos::main]
async fn main(spawner: Spawner) {
    // generator version: 0.5.0

    let config = esp_hal::Config::default().with_cpu_clock(CpuClock::max());
    let peripherals = esp_hal::init(config);

    let peripherals = create_peripherals(peripherals);
    debug!("Main: peripherals initialized");

    let timer0 = TimerGroup::new(peripherals.timer0);
    let sw_int = SoftwareInterruptControl::new(peripherals.sw_interrupt);
    esp_rtos::start(timer0.timer0, sw_int.software_interrupt0);
    debug!("Main: RTOS started");

    let rtc = mk_static!(
        RefCell<Rtc<'static>>,
        RefCell::new(Rtc::new(peripherals.lpwr))
    );
    let rtc: &'static RefCell<Rtc<'static>> = &*rtc;

    esp_alloc::heap_allocator!(#[esp_hal::ram(reclaimed)] size: 65536);
    esp_alloc::heap_allocator!(size: 65536);
    debug!("Main: heap allocators initialized");

    info!("Main: Embassy initialized!");

    // ====== DRIVERS ======

    debug!("Main: initializing SPI bus");
    let shared_bus = spi_bus::make_shared_spi(
        peripherals.spi_spi2.into(),
        peripherals.spi_dma.degrade(),
        peripherals.spi.sck,
        peripherals.spi.mosi,
        peripherals.spi.miso,
    );
    debug!("Main: SPI bus created, initializing SD card");
    let sd = Sd::new(shared_bus, peripherals.sd_cs).await;

    debug!("Main: SD card ready, initializing filesystem");
    let (device_config, fs) = sd.init().await;
    let fs = mk_static!(SdFsWrapper, fs);
    info!("Main: Config: {:?}", &device_config);

    info!("Main: Initializing player");
    let player = Player::new(
        peripherals.player_i2s.into(),
        peripherals.player_dma,
        peripherals.player.bclk,
        peripherals.player.ws,
        peripherals.player.dout,
        peripherals.audio_enable,
    );

    info!("Main: Initializing charger monitor");
    let charger = Charger::new(peripherals.charger.pin, peripherals.charger.connected_level);

    info!("Main: Initializing indicator LED");
    let indicator = IndicatorLed::new(peripherals.radio.pin);

    info!("Main: Initializing radio");
    let radio = firmware::drivers::radio::Radio::new(peripherals.radio_wifi);

    info!("Main: Initializing controls");
    let btn_play_pause = Button::new(peripherals.controls.btn_a).with_long_press(1500);
    let btn_next_prev = Button::new(peripherals.controls.btn_b).with_long_press(1500);
    let btn_vol_down = Button::new(peripherals.controls.btn_c).with_repeat(500);
    let btn_vol_up = Button::new(peripherals.controls.btn_d).with_repeat(500);

    info!("Main: Initializing RFID");
    let rfid = Rfid::new(
        shared_bus,
        peripherals.rfid_cs,
        peripherals.rfid_irq,
        peripherals.rfid_enable,
    )
    .await;

    // Spawn driver tasks
    let player_handle = PlaybackController::new(player, fs).spawn(&spawner);
    let mut charger_monitor = charger.spawn(&spawner);
    let indicator_handle = indicator.spawn(&spawner);
    let radio_handle = radio.spawn(&spawner).await;
    let rfid_handle = rfid.spawn(&spawner);
    debug!("Main: all driver tasks spawned");

    // ====== CONTROLLERS ======

    info!("Main: Starting WiFi manager");
    let wifi_handle = firmware::controllers::wifi::WifiManager::new().spawn(
        &spawner,
        radio_handle,
        indicator_handle,
        device_config,
        charger_monitor.clone(),
        rtc,
    );

    info!("Main: Starting network controller");
    NetworkController::new().spawn(
        &spawner,
        wifi_handle.clone(),
        fs,
        player_handle.clone(),
        rfid_handle.clone(),
    );

    info!("Main: Starting buttons task");
    Buttons::new(rtc, btn_play_pause, btn_next_prev, btn_vol_down, btn_vol_up).spawn(
        &spawner,
        wifi_handle.clone(),
        player_handle.clone(),
    );

    debug!("Main: all controllers spawned, entering main loop");
    loop {
        rfid_handle.trigger_scan();

        let mut is_playing = player_handle.status().get_playback_status().state == State::Playing;
        let is_charging = charger_monitor.is_connected();
        let is_wifi_active = wifi_handle.is_wifi_active();
        debug!(
            "Main: scan loop - is_playing={}, is_charging={}, is_wifi_active={}",
            is_playing, is_charging, is_wifi_active
        );

        let scan_interval_ms = match rfid_handle.wait_for_scan_result().await {
            firmware::drivers::rfid::RfidScanResult::Found(fob) => {
                player_handle
                    .play_playlist_ref(firmware::entities::playlist::PlayListRef::new(fob))
                    .await;
                is_playing = true;

                5000
            }
            firmware::drivers::rfid::RfidScanResult::NotFound => 500,
            firmware::drivers::rfid::RfidScanResult::Error => 1000,
        };

        if is_charging || is_playing || is_wifi_active {
            Timer::after(Duration::from_millis(scan_interval_ms)).await;
        } else {
            let timer_wakeup =
                TimerWakeupSource::new(Duration::from_millis(scan_interval_ms).into());
            let gpio_wakeup = GpioWakeupSource::new();
            rtc.borrow_mut().sleep_light(&[&timer_wakeup, &gpio_wakeup]);

            let source = wakeup_cause();
            if matches!(source, SleepSource::Gpio) {
                Timer::after(Duration::from_millis(500)).await;
            }
        }
    }
}

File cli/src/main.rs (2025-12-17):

use clap::{Parser, Subcommand};
mod commands;
use commands::transcode::TranscodeCommand;

#[derive(Parser)]
#[command(name = "pecli")]
#[command(about = "PhoniESP32 CLI tool")]
#[command(version = "0.1.0")]
struct Cli {
    #[command(subcommand)]
    command: Commands,
}

#[derive(Subcommand)]
enum Commands {
    Transcode(TranscodeCommand),
}

#[tokio::main]
async fn main() -> Result<(), Box<dyn std::error::Error>> {
    let cli = Cli::parse();

    match cli.command {
        Commands::Transcode(cmd) => cmd.execute().await?,
    }

    Ok(())
}

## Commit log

2025-10-11 chore(wip): switch to embedded-fatfs (async)
2025-10-12 Revert "feat(wip): copy basic rfid reading example" because is causing interference on i2s
    This reverts commit c66af3195243262b6cdaad84759a3f0e61996aa4.
    [main.rs]
2025-10-28 feat: RFID controls
    This reverts commit 6b5cce0e0bcfc6538ce187b48862e8c22f9d9b72.
    [main.rs, rfid.rs]
2025-11-08 chore(firmware): switch to upstream embedded-fatfs
2025-11-11 chore(web): proxy /api to device
2025-12-02 fix(firmware): synchronized filesystem access
    [main.rs]
2025-12-30 chore(wip): use esp32-c6
2025-12-30 chore(firmware): shared spi bus
2026-02-09 fix(firmware): fix justfile for esp32-c6
2026-02-17 feat(firmware): use new async mfrc522 driver
2026-02-17 feat(firmware): power state controls wifi
2026-02-17 feat(firmware): re-enable controls with long/short press and repeat
    [main.rs]
2026-02-17 fix(firmware): debounce key presses
    [main.rs]
2026-02-18 chore(firmware): reassign button and power detection pins to allow wakeup from LP
2026-02-22 chore(firmware): reassign pins for easier board layout
2026-02-28 feat(case): prototype case
    [PrototypeCase.FCStd]
2026-03-02 feat(pcb): initial schematic
    [I2S.kicad_sch, PhoniESP32.kicad_pcb, PhoniESP32.kicad_sch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]
2026-03-02 fix(pcb): add power flags for ERC
    [I2S.kicad_sch, Power.kicad_sch]
2026-03-02 feat(pcb): add power switch
    [Power.kicad_sch]
2026-03-02 fix(pcb): add 22 Ohm resistors on USB data lines
    [PhoniESP32.kicad_sch, Power.kicad_sch]
2026-03-02 chore(pcb): make charging indicator LEDs brighter
    [Power.kicad_sch]
2026-03-03 feat(pcb): initial layout
    [PhoniESP32.kicad_pcb]
2026-03-04 feat(pcb): place test points and placeholders
    [I2S.kicad_sch, PhoniESP32.kicad_pcb, PhoniESP32.kicad_sch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]
2026-03-04 feat(pcb): initial traces
    [PhoniESP32.kicad_pcb, PhoniESP32.kicad_sch, Power.kicad_sch]
2026-03-05 chore(pcb): add bigger copper areas for power distribution
    [I2S.kicad_sch, PhoniESP32.kicad_pcb, Power.kicad_sch]
2026-03-05 chore(pcb): final cleanups
    [I2S.kicad_sch, PhoniESP32.kicad_pcb]
2026-03-05 chore(pcb): ignore JLCPCB outputs
2026-03-12 fix(pcb): minor revisions by external reviewer
    [I2S.kicad_sch, PhoniESP32.kicad_pcb]
2026-03-12 fix(pcb): resolve via spacing warning
    [PhoniESP32.kicad_pcb]
2026-03-13 chore(pcb): switch from PCB antenna to connector
    [PhoniESP32.kicad_pcb, PhoniESP32.kicad_sch]
2026-03-18 chore(firmware): remove debug print during upload
2026-03-26 feat(firmware): add pin mapping for PCB
2026-04-03 chore(pcb): update to KiCad 10
    [I2S.kicad_sch, PhoniESP32.kicad_pcb, PhoniESP32.kicad_sch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]
2026-04-03 fix(pcb): swap pin connector for header
    [PhoniESP32.kicad_pcb]
2026-04-15 feat(case): create case
    [PCBCase.FCStd]
2026-04-28 feat(firmware): light sleep between scans when not charging
2026-05-10 fix(firmware): wake up from light sleep on button press
    [main.rs]
2026-06-02 feat(firmware): WiFi override via volume buttons
2026-06-02 fix(firmware): various bugs found during testing
    [audio.rs]
2026-06-02 fix(firmware): no light sleep if WiFi is active
    [main.rs]
2026-06-02 fix(firmware): Use RTC to detect WiFi override timeout
    [main.rs]
2026-06-02 chore(docs): PCB build instructions
2026-07-03 feat(pcb): version for hand soldering
    [I2S.kicad_sch, PhoniESP32.kicad_pcb, PhoniESP32.kicad_sch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]
2026-07-03 feat(pcb): add labels for basic components
    [PhoniESP32.kicad_pcb]
